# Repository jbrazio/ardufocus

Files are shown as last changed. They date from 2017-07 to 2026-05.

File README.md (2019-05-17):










**Ardufocus - The most accurate Open Source focus controller.**

Ardufocus is the only OSS/OSH controller supporting **two independent** focusing motors, **high resolution**
mode allowing **sub μm** movements by step, multiple acceleration profiles and it will never forget your
focuser position between restarts.

Ardufocus is a multi repository project:
- [Ardufocus firmware](https://github.com/jbrazio/ardufocus)
- [Ardufocus schematics](https://github.com/jbrazio/ardufocus-schematics)
- [Ardufocus ASCOM IFocuserV3 Driver](https://github.com/jbrazio/ardufocus-ascom)

Ardufocus is licensed under [GNU GPLv3](https://www.gnu.org/licenses/gpl-3.0.en.html). <br />
Ardufocus PCB schematics are licensed under [CC BY-NC-SA 4.0](https://creativecommons.org/licenses/by-nc-sa/4.0/).

----

### For documentation, tutorials and howto visit [ardufocus.com](https://ardufocus.com).

----

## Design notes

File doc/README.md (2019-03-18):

# Disclaimer

Unless otherwise noted, all materials contained in this repository are copyrighted
Copyright (C) 2017-2019 João Brázio [joao@brazio.org] and licensed under GPLv3.

The following materials are property of their respective owners:

- 28byj-48-bipolar-mod.pdf
- moonlite-dro-dual-focuser.pdf
- moonlite-focuser-protocol.pdf

## Fair Use

Copyright Disclaimer under section 107 of the Copyright Act of 1976, allowance
is made for “fair use” for purposes such as criticism, comment, news reporting,
teaching, scholarship, education and research.

## Fair Use Definition

Fair use is a doctrine in United States copyright law that allows limited use
of copyrighted material without requiring permission from the rights holders,
such as commentary, criticism, news reporting, research, teaching or scholarship.
It provides for the legal, non-licensed citation or incorporation of copyrighted
material in another author’s work under a four-factor balancing test.

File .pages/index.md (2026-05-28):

---
layout: homepage
keywords:

title: Ardufocus
description: |
  Ardufocus is the only OSS/OSH controller supporting <strong>two independent </strong>
  focusing motors, <strong>high resolution</strong> mode allowing <strong>sub μm</strong> movements
  by step, multiple acceleration profiles and it will never forget your focuser position between restarts.

buttons:
    - icon: chevron-right
      content: Firmware
      url: 'https://github.com/jbrazio/ardufocus/releases'
      external_url: true

    - icon: chevron-right
      content: Schematics
      url: 'https://github.com/jbrazio/ardufocus-schematics/releases'
      external_url: true

    - icon: chevron-right
      content: ASCOM Driver
      url: 'https://github.com/jbrazio/ardufocus-ascom/releases'
      external_url: true

author:
    title: About the Author
    title_url: 'https://github.com/jbrazio'
    external_url: true
    description: Nerd, geek, maker and part-time human being.

grid_navigation:
    - title: Getting started
      excerpt: >
        In this section you'll find basic information about Ardufocus. If you're first time user
        then you should read Getting Started section first.
      cta: Read more
      url: '/manual/getting-started/'

    - title: Hardware
      excerpt: >
        In this section we layout a quick overview of the main hardware used by Ardufocus so you can
        select the best hardware combination for your use case.
      cta: Read more
      url: '/manual/hardware/'

    - title: Build instructions
      excerpt: >
        It's time to get your hands dirty, learn which components you require for this
        project and learn howto build one for yourself.
      cta: Read more
      url: '/manual/build-instructions/'

    - title: Firmware
      excerpt: >
        In this section you'll find all the information you need to know to build and flash
        Ardufocus into your Arduino board.
      cta: Read more
      url: '/manual/firmware/'

    - title: ASCOM Driver
      excerpt: >
        This section will guide you around the ASCOM driver installation, a tour around the simple
        GUI and example configurations for common capture software.
      cta: Read more
      url: '/manual/ascom-driver/'

    - title: Tutorials
      excerpt: >
        Miscellaneous group of documents were each document will stand on it's own and will provide
        step by step instructions on how to do accomplish something.
      cta: Open Category
      url: '/howto/'
---

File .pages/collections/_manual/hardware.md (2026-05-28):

---
layout: default
keywords:
comments: false

tags: [ manual ]

title: Hardware
description: >
  In this section we layout a quick overview of the main hardware used by Ardufocus so you can
  select the best hardware combination for your use case.

micro_nav: true

page_nav:
    prev:
        content: Getting Started
        url: '/manual/getting-started/'

    next:
        content: Build instructions
        url: '/manual/build-instructions/'
---

### Processor
Ardufocus firmware supports the following AVR 8-bit microcontrollers. Currently there are no plans
to support additional architectures such as ARM but if you have a specific use case for it open a
[new feature request] and we will discuss it.

[new feature request]: {{ site.github.issues_url }}

| Microcontroller | Flash | SRAM  | EEPROM  |
|---|---|---|---|
| ATmega168 | 16KB  | 1KB | 512B |
| ATmega168P | 16KB  | 1KB | 512B |
| ATmega328P | 32KB  | 2KB |  1KB |
| ATmega328PB | 32KB  | 2KB |  1KB |
| ATmega32U4 | 32KB  | 2.5KB |  1KB |

Ardufocus uses as the brain for the operations the Arduino development board but the Arduino framework
aka IDE is not a build dependency for this project. Ardufocus is written in AVR C++.

The following boards have been tested and are fully supported:

| Board Name | Microcontroller | Clock  | Logic |
|---|---|---|---|
| Arduino UNO | ATmega328P | 16 MHz | 5V  |
| Arduino Nano 2.0 | ATmega168 | 16 MHz | 5V  |
| Arduino Nano 3.0 | ATmega328P | 16 MHz | 5V  |
| Arduino Nano 3.0 CN | ATmega328PB | 16 MHz | 5V  |
| Arduino Mini | ATmega168P | 16 MHz | 5V  |
| Arduino PRO Mini | ATmega328P | 16 MHz | 5V  |
| Sparkfun PRO Mini 3.3V | ATmega32U4 |  8 MHz | 3.3V  |

The serial support for the Sparkfun PRO Mini board is only avaliable for the internal *USART1*
broken out on pins `TX0` and `RX1`.

Some Arduino Nano clones coming from China use the *ATmega328PB* variant, despite being compatible
with the standard *ATmega328P* you may have some trouble getting the Arduino IDE to upload the
sketch into them. If this is your case [follow this tutorial] about properly stetting up the IDE
environment for working with those micros.

[follow this tutorial]: #

<div class="callout callout--warning">
  <p><strong>Memory constrains</strong> The usage of a microcontroller with less than 32KB of
  flash memory is currently barely supported as the firmware will use almost all of the available
  flash space. For future proof implementations it is strongly recommended to use one of the 32KB
  based boards.</p>
</div>

We recommend the usage of an [Arduino Nano 3.x] board.
This is a compact board, has enough *DIO* pins to handle two independent focuser motors and has
on-board Serial USB connectivity.

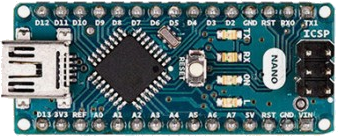
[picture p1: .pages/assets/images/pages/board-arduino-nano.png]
Arduino Nano


[Arduino Nano 3.x]: https://www.banggood.com/3Pcs-ATmega328P-Nano-V3-Controller-Board-Compatible-Arduino-Improved-Version-p-983486.html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

The following table represents the translation between IO `pins` as defined on the Arduino lingo and
their numeric equivalent on the Ardufocus configuration files, it also list the `pin` type and if it
defined on the Ardufocus's Hardware Abstraction Layer (HAL), pins not defined on the HAL are not
usable.

| Type | Arduino | PIN | HAL |
|---|---|-----|-----|
| Digital | D0 | 0 | Yes |
| Digital | D1 | 1 | Yes |
| Digital | D2 | 2 | Yes |
| Digital | D3 | 3 | Yes |
| Digital | D4 | 4 | Yes |
| Digital | D5 | 5 | Yes |
| Digital | D6 | 6 | Yes |
| Digital | D7 | 7 | Yes |
| Digital | D8 | 8 | Yes |
| Digital | D9 | 9 | Yes |
| Digital | D10 | 10  | Yes |
| Digital | D11 | 11  | Yes |
| Digital | D12 | 12  | Yes |
| Digital | D13 | 13  | Yes |
| Analog  | A0 | 14  | Yes |
| Analog  | A1 | 15  | Yes |
| Analog  | A2 | 16  | Yes |
| Analog  | A3 | 17  | Yes |
| Analog  | A4 | 18  | Yes |
| Analog  | A5 | 19  | No  |
| Analog  | A6 | 20  | No  |
| Analog  | A7 | 21  | No  |

### Stepper driver

| Driver | Current | Microsteps | VCC |
|---|---|---|---|
| [A4988] | 2A | 16 | 8-35V |
| [DRV8825] | 2.5A | 32 | 8-45V |
| [ULN2003] | 0.5A | 1 | 5-50V |

<div class="callout callout--info">
  <p><strong>ULN2003</strong> Actually the ULN2003 isn't a stepper motor driver but instead
  a Darlington Transistor Array on a single IC package thus all the pulse-train's timming and any
  additional microstepping needs to be generated by the microcontroller.</p>
</div>

Due to the wide usage of "step sticks" on 3D printers, the price difference between them and simpler
ULN2003 are virtually negligible when sourcing from generic manufacturers.

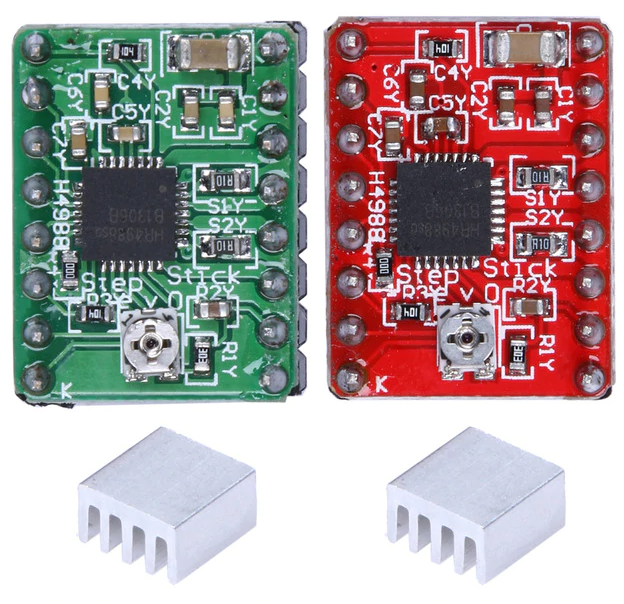
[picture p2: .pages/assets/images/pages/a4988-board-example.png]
A4988


The A4988 or the DRV8825 stepper motor driver have a lot of advantages when compared with the
ULN2003 darlington transistor array:

- Microstepping
- Adjustable current limiting
- Over-current and over-temperature protection
- 8-25V @ 1A without requiring a heat sink or forced air flow

[A4988]: https://www.banggood.com/3Pcs-3D-Printer-A4988-Reprap-Stepping-Stepper-Step-Motor-Driver-Module-p-967057.html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
[DRV8825]: https://www.banggood.com/3Pcs-3D-Printer-Stepstick-DRV8825-Stepper-Driver-Reprap-4-Layer-PCB-p-1052018.html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
[ULN2003]: https://www.banggood.com/3pcs-ULN2003-Four-phase-Five-wire-Driver-Board-Electroincs-Stepper-Motor-Driver-Board-p-1352783.html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

### Stepper motor
Ardufocus supports two types of stepper motors depending on the selected stepper driver.
Bipolar stepper motors are commonly known as [NEMA17] and have four leads.
Unipolar stepper motors are more uncommon and have five leads, the best known example is the [28BYJ-48].

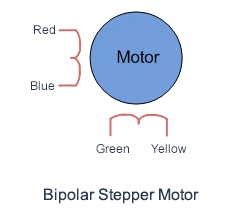
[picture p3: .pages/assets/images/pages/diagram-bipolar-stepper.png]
Bipolar Stepper Motor

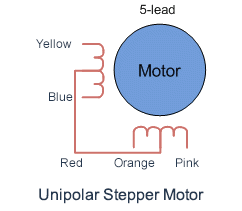
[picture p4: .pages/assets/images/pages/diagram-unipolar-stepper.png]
Unipolar Stepper Motor


Step stick drivers such as the A4988 or DRV8825 will drive Bipolar Stepper Motors like most
NEMA17 motors. The ULN2003 can drive either motor type but Ardufocus only supports Unipolar
Stepper motors when using the ULN2003 driver.

Unipolar stepper motors such as the 28BYJ-48 can be physically converted into a Bipolar type.
For more information have a look at the [following guide].

The table bellow represents typical values for both stepper motor types, you should always confirm
the specs for your specific motor by reading the manufacturer data sheet. Only for reference I provide
links for very common models of the [NEMA17](https://www.sparkfun.com/datasheets/Robotics/SM-42BYG011-25.pdf)
and [28BYJ-48](http://www.geeetech.com/Documents/Stepper%20motor%20datasheet.pdf) stepper motors.

| Type | I | Angle | Torque  | Gear | Steps/Rev |
|---|---|---|---|---|---|
| Bipolar  | 0.9A | 0.9 | 0.34N.M | 1:1  | 200 |
| Unipolar | 0.2A | 5.625 | 0.08N.M | 64:1 | 2038 |

<div class="callout callout--danger">
  <p><strong>Stepper motor voltage</strong> If you intend to use an Unipolar motor with the ULN2003
  driver please pay special attention to the motor's nominal voltage because this driver does not allow
  the user to set a current limit. 28BYJ-48 stepper motors are commonly available at 5V and 12V
  ratings, we recommend the 12V version.</p>
</div>

In terms of pricing, [NEMA17] motors are much more expensive than the [28BYJ-48]. You can buy a
[NEMA17] in the $15 range while a [28BYJ-48] motor will cost you only $2.

The main advantage of using a NEMA17 is the 5% accuracy range per step and the higher torque which
allows heavier payloads. As it is recommended to use backlash compensation on the focusing software,
the step accuracy between the two motor types is not that relevant.

[NEMA17]: https://www.banggood.com/FLSUN-2PCS-4-LEAD-Nema17-42BYGH-1_7A-Stepper-Motor-For-3D-Printer-p-1263976.html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
[28BYJ-48]: https://www.banggood.com/KittenBot-2Pcs-28BYJ-48-5V-DC-Stepper-Motor-4-Phase-5-Line-for-Smart-Robot-DIY-Part-p-1287817.html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
[following guide]: {{ '/howto/28BYJ-48-bipolar-hw-mod/' | relative_url }}

### Temperature sensor

<div class="callout callout--warning">
  <p><strong>TODO</strong> This section needs further improvement.</p>
</div>

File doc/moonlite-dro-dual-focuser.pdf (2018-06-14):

## Using a MoonLite DRO Dual controller with two

focusers.

Introduction.
It is possible to use the MoonLite DRO Dual port controller with two focusers rather than the normal configuration of one focuser and one rotator. This paper describes how to do this.
This control is only available through the ASCOM driver. The stand alone driver assumes that the second port is connected to a rotator.
Set up.
- Install the ASCOM DRO focuser and rotator driver.
- Select both the second Focuser and the second Rotator options, even though you don’t plan to use the rotator. The driver will try to connect as a rotator because it doesn’t know that one is not required.

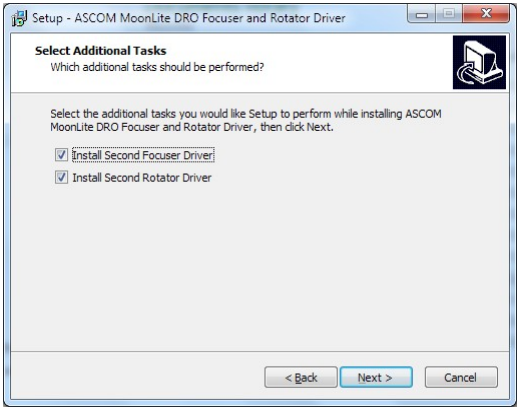
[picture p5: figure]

- Connect the two focusers, one to each port.
- For the first focuser:
- Select MoonLite DRO Focuser Driver
- Click on Properties:

- Set Motor 1 to be a focuser and set up the focuser:

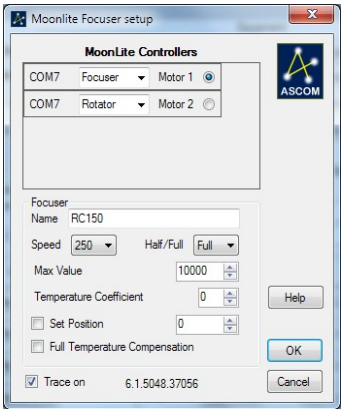
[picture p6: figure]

- Click on OK.
- For the second focuser:
- Select Second MoonLite DRO Focuser Driver
- Click on Properties:

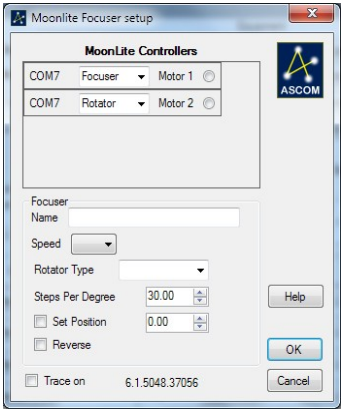
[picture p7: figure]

- Use the combo box to set Motor 2 to be a Focuser instead of a rotator and select it:

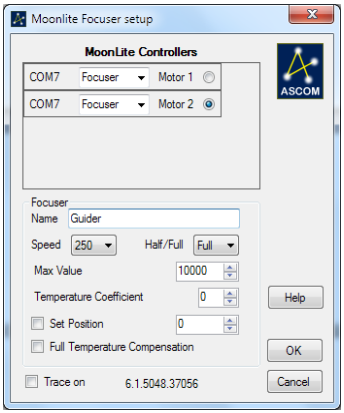
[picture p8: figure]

- Set up the values, including the name for that focuser and click on OK.

You should now be able to connect to and control both focusers.

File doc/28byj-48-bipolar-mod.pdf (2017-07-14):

ZONDAG 27 OKTOBER 2013
Change unipolar 28BYJ-48 to bipolar stepper motor
Now here's something I was not expecting. Previously, I tried to drive this stepper motor (http://www.jangeox.be/2013/10/stepper-motor-28byj-48_25.html) with the driver board that came with the motor. My main goal was of course keeping the accuracy of the tiny motor safe and then testing at which speed I could get the maximum torque it could produce. Depending on the driving method, I came up with 300gcm when it was driven using half stepping and 380gcm when I switched to full stepping. Those were actually good results considering that the datasheet predicted these numbers more or less.

Now this kind of motor is not really up-to-date with modern technology. Unipolar stepper motors are not that common anymore. Bipolar steppers are twice as efficient with the same amount of copper on the internal windings. Even in full stepping mode, a unipolar stepper still has 2 out of four wires not active all the time. So basically, if there was a way to run current through all windings in the motor at all times, the thing would be stronger and faster.

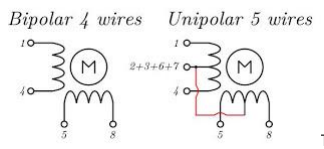
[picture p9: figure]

That's what happens in a bipolar stepper motor. It has only two windings instead of four in a unipolar stepper. Both windings can be activated all the time, but their polarity is switched in four steps. This means that this kind of motor only has four wires instead of 5 (or 6 or 8). The tricky part is changing the polarity. That cannot be achieved by the simple driver board that came with this motor. It only activates one or two out of four outputs, but current always flows in one direction.

What if we could change the wiring of this motor, thus converting it to a bipolar model? All you would need to do is cut the red wire in the scheme above and then ignore the center connection marked 2+3+6+7. The result would be something like the left drawing.

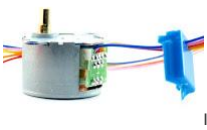
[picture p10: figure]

I found out that this is very easy with this motor. All you need is a sharp knife and a tiny screwdriver. Use the latter to remove the blue plastic cap that hides a small PCB. On this PCB, you can see eleven solder points. All it does is fixate the wiring of this stepper (which can be either unipolar or bipolar by design) into a unipolar type by connecting the center of the two windings. If we cut this connection and ignore it in our scheme, what's left is a real bipolar stepper motor.

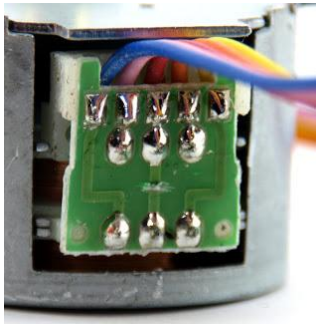
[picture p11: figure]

This is what the PCB looks like in detail. The red connection in the scheme above is actually the copper connection in this picture that I cut with a cutter knife. That's all you need to do! Well, for your own peace of mind, you could also try to re-attach the blue plastic cover. And now, ignore the red wire of the motor. We don't need it anymore.

But now we have a motor without a driver board. What you need is a H-bridge type which luckily exists in small packages if you're not going to drive heavy machinery. I used a L293D 16 pins DIP chip which I found online for $5.5 for ten chips.

I drew up this scheme that I used to drive the motor with an Arduino (actually I used an Atmega8 on a breadboard doing exactly the same thing, only a bit slower). I'm using 9V on the motor in this test since windings are twice as long as in the original version. I guess you could go much higher than that, this thing never heated up in my test.

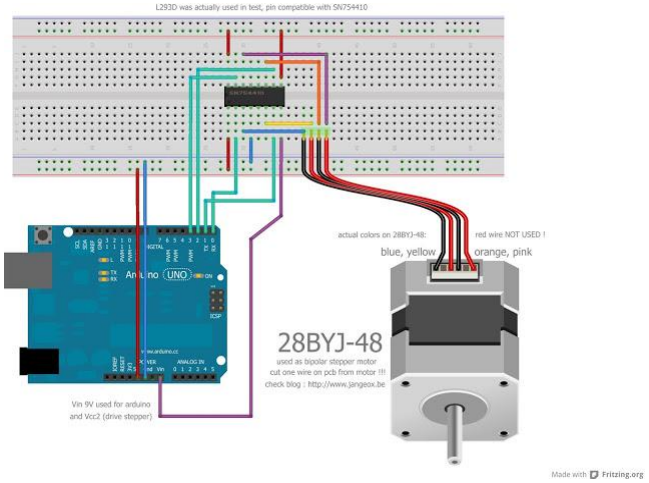
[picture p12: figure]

My simple code example to drive it can be found here. (http://printplussupport.be/28BYI_48_bipolar.html)

Finally, most importantly, my torque test resulted in :

800gcm !!

which is at least twice as much as full stepping unipolar (380gcm) and almost 3x more powerful than my half stepping unipolar test (300gcm)

Basically, if I cut one wire in the motor, it gains almost 3 times its original strength.

I like it! A lot! :)

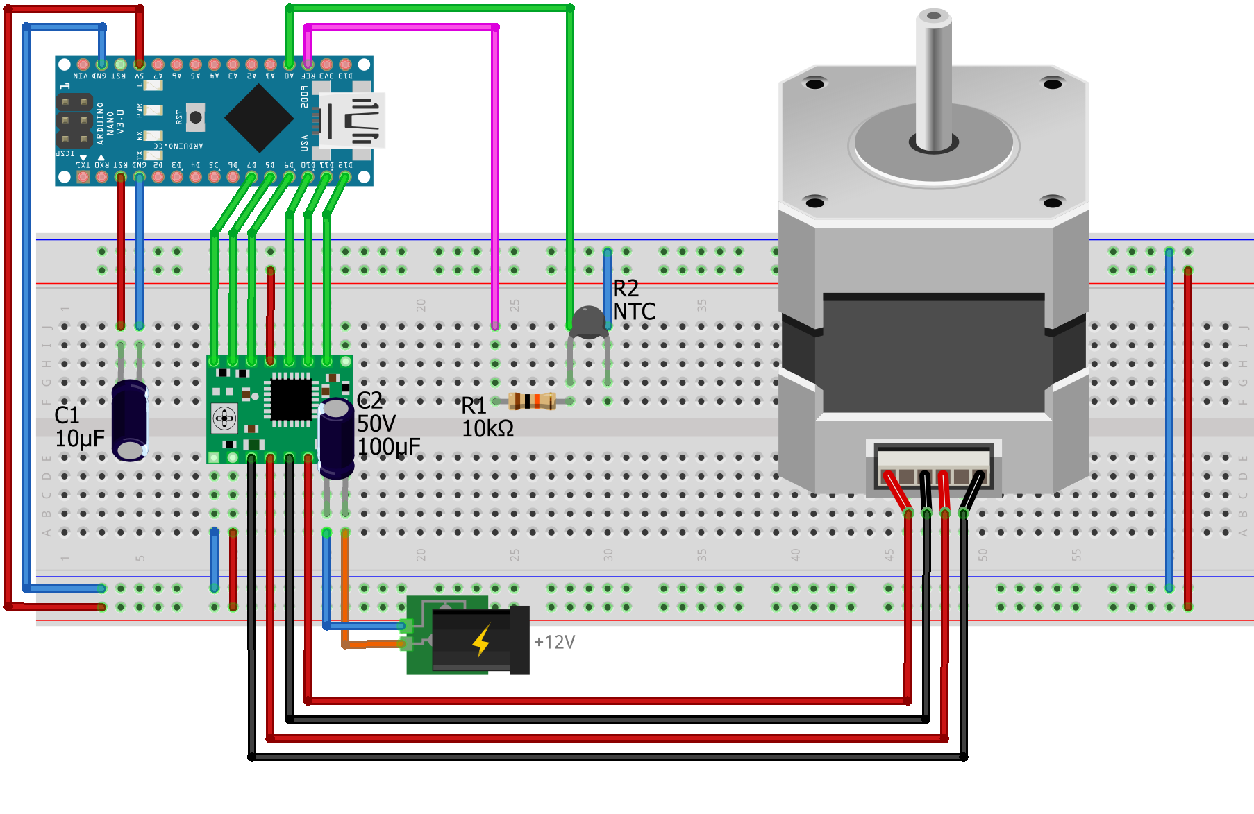
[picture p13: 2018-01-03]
doc/wiki/schematic-bipolar_bb.png

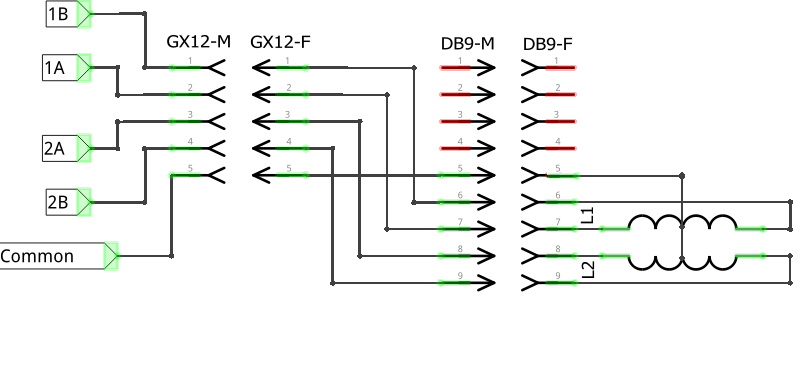
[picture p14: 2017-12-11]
doc/wiki/pinout-unipolar.png

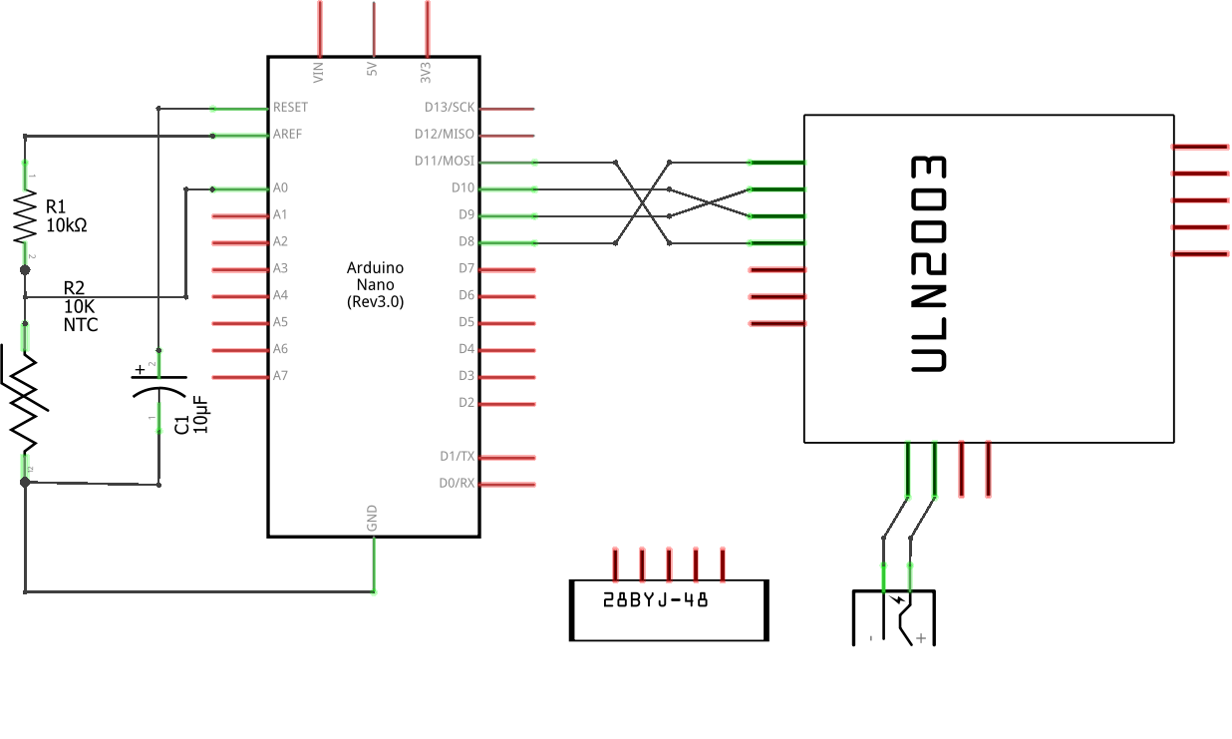
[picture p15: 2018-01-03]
doc/wiki/schematic-unipolar_schem.png

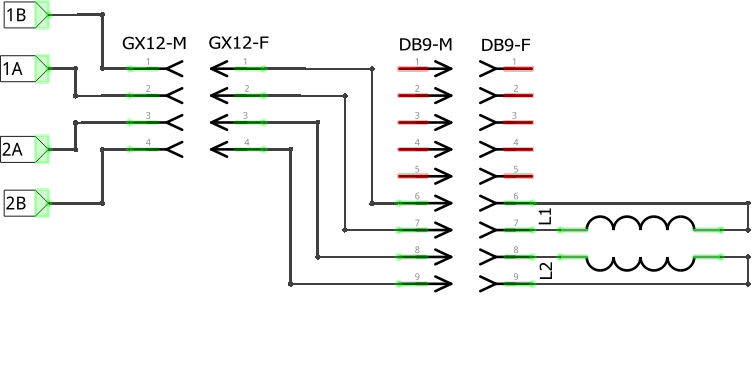
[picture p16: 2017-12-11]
doc/wiki/pinout-bipolar.png

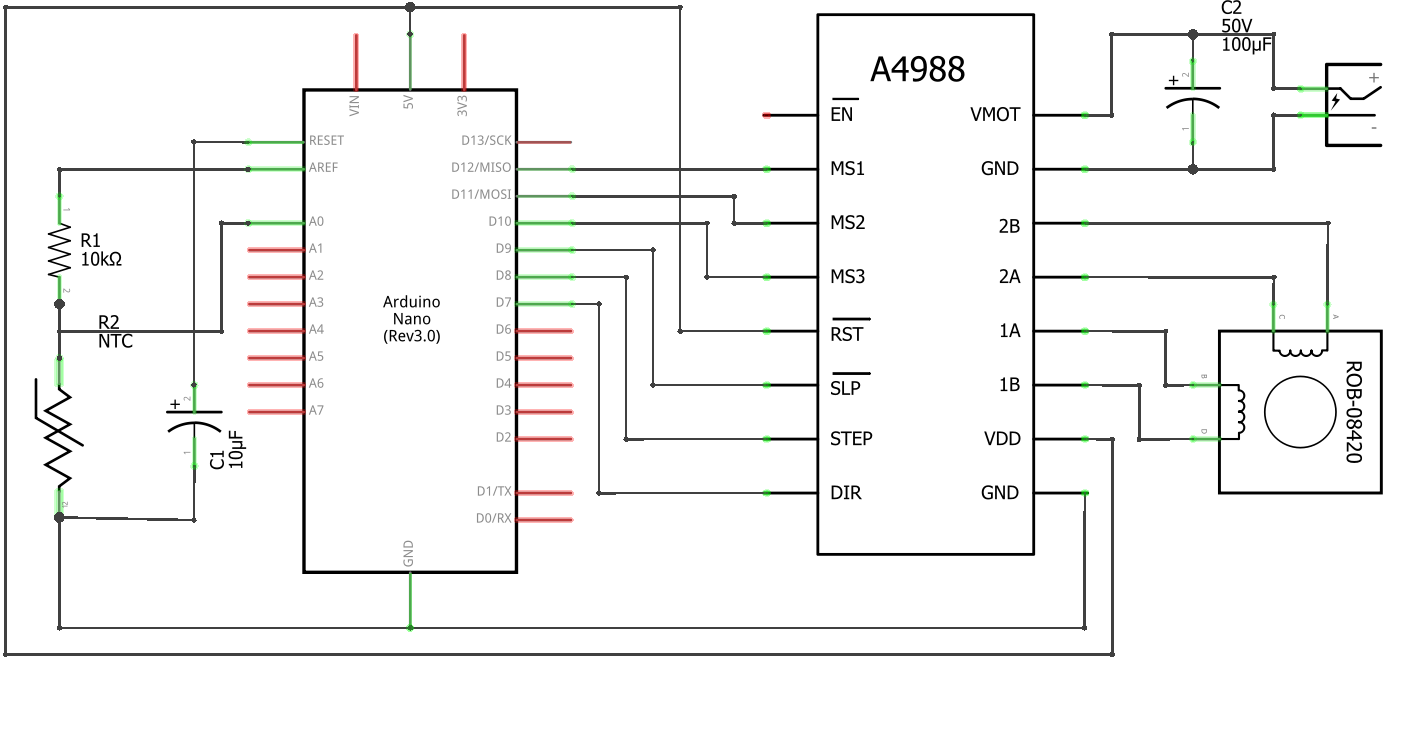
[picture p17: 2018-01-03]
doc/wiki/schematic-bipolar_schem.png

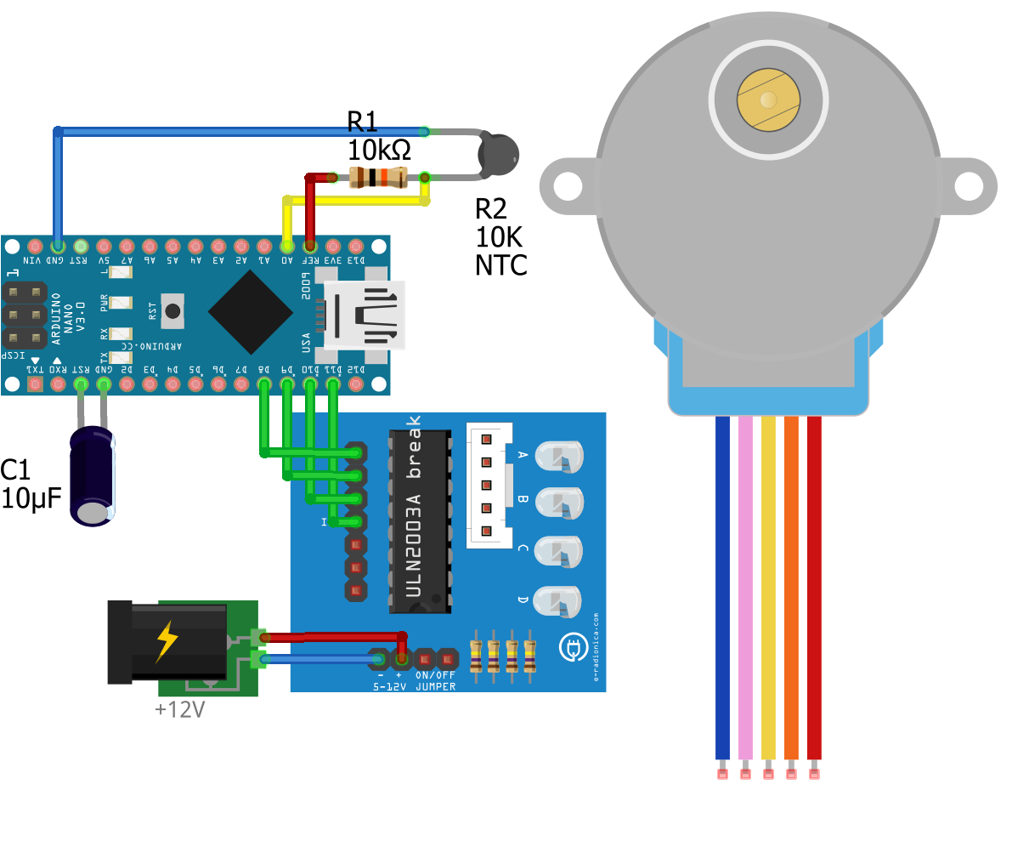
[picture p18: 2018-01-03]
doc/wiki/schematic-unipolar_bb.png

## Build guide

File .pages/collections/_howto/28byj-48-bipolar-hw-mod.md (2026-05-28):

---
layout: default
keywords:
comments: false

tags: [ howto ]

title: 28BYJ-48 Bipolar Mod
description: >
  This tutorial will teach you how you can convert easily the Unipolar 28BYJ-48 stepper motor into
  a Bipolar one.

micro_nav: true
---

## Introduction
The [28BYJ-48] is out of the factory a Unipolar Stepper Motor which, nowadays, are not that common
anymore. Bipolar stepper motors are considered to be at least twice as efficient as an Unipolar motor
for the same amount of copper on the windings.

Bipolar Stepper Motor
Unipolar Stepper Motor

According to [research done by Jan Adriaensen] the [28BYJ-48] in an Unipolar configuration can produce
300g.cm of torque half stepped and 380g.cm when full stepped, after the Bipolar mod you can expect
the motor to produce **800g.cm** of torque, that's around 3x more efficient !

[research done by Jan Adriaensen]: http://www.jangeox.be/2013/10/stepper-motor-28byj-48_25.html

## Modding the motor
To perform the hardware mode is quite simple, just pry open the blue plastic cover having special
attention not to hurt yourself, there are two plastic tabs one on each side of the cover which need
to break free in order for the cover to come out. This may require a bit of force.

After the cover is out the PCB will be exposed, you'll see three main thick traces, take a hobby
knife and cut the middle trace by scrapping the PCB varnish and copper. In the end you should have
a 1-2mm gap on the trace.

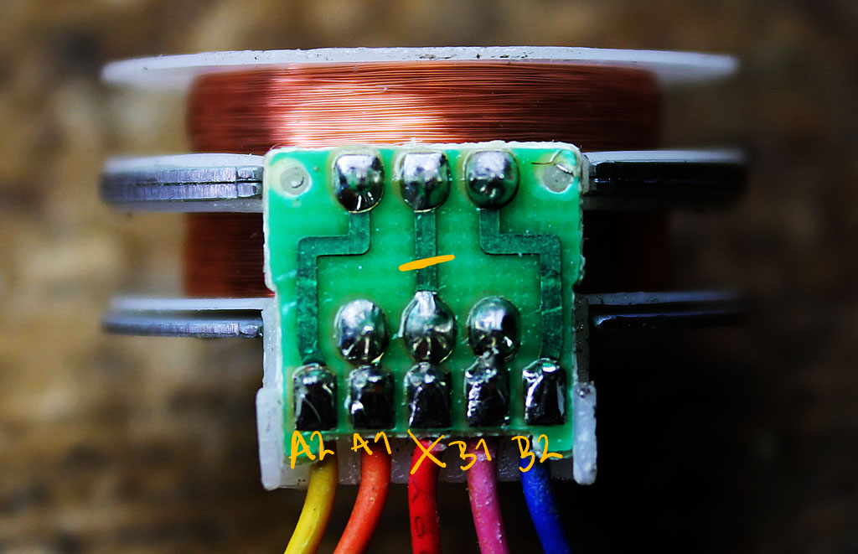
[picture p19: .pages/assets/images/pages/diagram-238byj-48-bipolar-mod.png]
PCB mod


The new motor windings will be **1** (Orange, Pink) and **2** (Yellow, Blue), you may cut the red
wire on unsolder it from the PCB.

| Color  | Winding | Side |
|---|---|---|
| Yellow | 2 | A |
| Orange | 1 | A |
| Red | N/A | N/A  |
| Pink | 1 | B |
| Blue | 2 | B |

## Driver
After performing the mod we can no longer use the [ULN2003] board to drive the stepper motor, we now
need a "H-Bridge" type of driver such as the [A4988] or the [DRV8825].

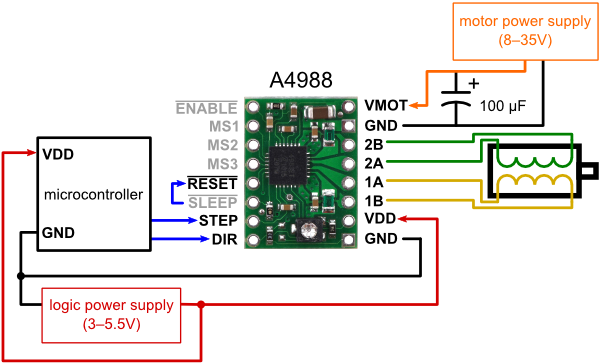
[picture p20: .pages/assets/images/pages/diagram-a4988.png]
A4988 schematic


[A4988]: https://www.banggood.com/3Pcs-3D-Printer-A4988-Reprap-Stepping-Stepper-Step-Motor-Driver-Module-p-967057.html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
[DRV8825]: https://www.banggood.com/3Pcs-3D-Printer-Stepstick-DRV8825-Stepper-Driver-Reprap-4-Layer-PCB-p-1052018.html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
[ULN2003]: https://www.banggood.com/3pcs-ULN2003-Four-phase-Five-wire-Driver-Board-Electroincs-Stepper-Motor-Driver-Board-p-1352783.html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
[28BYJ-48]: https://www.banggood.com/KittenBot-2Pcs-28BYJ-48-5V-DC-Stepper-Motor-4-Phase-5-Line-for-Smart-Robot-DIY-Part-p-1287817.html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

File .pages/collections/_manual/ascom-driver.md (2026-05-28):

---
layout: default
keywords:
comments: false

tags: [ manual ]

title: ASCOM Driver
description: >
  This section will guide you around the ASCOM driver installation, a tour around the simple
  GUI and example configurations for common capture software.

micro_nav: true

page_nav:
    prev:
        content: Firmware
        url: '/manual/firmware/'

    next:
        content: Tutorials
        url: '/howto/'
---

<div class="callout callout--warning">
  <p><strong>TODO</strong> This section needs further improvement.</p>
</div>

Ardufocus is 100% compatible with the Moonlite focuser protocol thus the original single-motor
drivers can be used for manual control of the unit, if you need to integrate with SGP, APT or any
other ASCOM based software then the universal ASCOM driver should be installed.

- [Moonlite's manual focus control](https://focuser.com/media/Downloads/MoonLite_Software/NonAscom/MoonliteSingleFocuser_v1.4.zip)
- [Moonlite's Universal ASCOM driver](https://focuser.com/media/Downloads/MoonLite_Software/Ascom/MoonLite%20DRO%20Setup.zip)

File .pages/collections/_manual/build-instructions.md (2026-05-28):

---
layout: default
keywords:
comments: false

tags: [ manual ]

title: Build instructions
description: >
  It's time to get your hands dirty, learn which components you require for this
  project and learn howto build one for yourself.

micro_nav: true

page_nav:
    prev:
        content: Hardware
        url: '/manual/hardware/'

    next:
        content: Firmware
        url: '/manual/firmware/'
---

## Motor Connections
### Unipolar

The Unipolar motor connection is straight forward because both the motor and the **ULN2003** board usually
come with a **JST-XH** connector. But nevertheless the table bellow lists the correct connections between
the two components.

| Color  | Winding | Side | ULN2003 |
|---|---|---|---|
| Blue | 2 | B | A |
| Pink | 1 | B | B |
| Yellow | 2 | A | C |
| Orange | 1 | A | D |
| Red | N/A | N/A  | +12V |

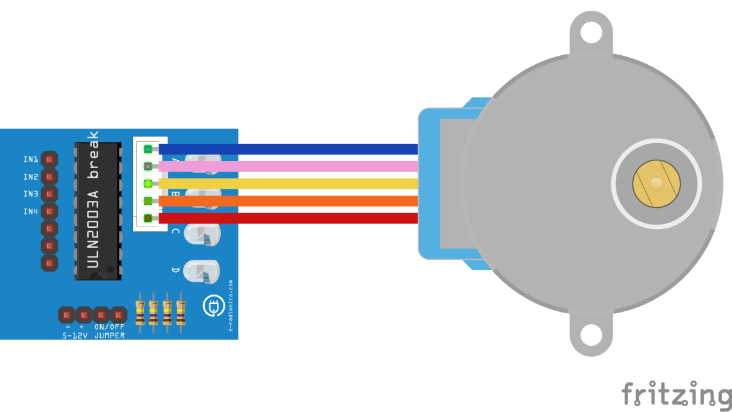
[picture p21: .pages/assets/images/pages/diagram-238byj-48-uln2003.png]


Remember to enable `#define MOTOR1_USE_ULN2003_DRIVER` on your `config.h` file, for more information
check the [firmware page].

### Bipolar
Bipolar stepper motors are only supported by Ardufocus when using a step stick, due to the multiple
motors and connectors available on the market it's hard to specify which one will be the correct one
in use at your configuration but nevertheless there are some tricks that will ease your job finding
the correct connections.

#### NEMA17
All NEMA motors have only four wires, to find the correct windings just grab your multimeter and set
it for resistance measurement. Label each one of the wires from 1 to 4 and then take any random two
and measure the resistance between them, either you'll get a reading or a open circuit. Keep
measuring different wires until you get the two pairs that give you a reading between them and that's
your two coils.

Let's assume wire `1 and 3` form a pair and `2 and 4` form the other pair, to connect it to the step
stick connect `wire 1` to `2B`, `wire 3` to `2A`, `wire 2` to `1B` and `wire 4` to `1A`.

#### 28BYJ-48

The table bellow shows the connections between the **28BYJ-48** motor and the **A4988** step stick.

| Color  | Winding | Side |
|---|---|---|
| Blue | 2 | B |
| Yellow | 2 | A |
| Orange | 1 | A |
| Pink | 1 | B |
| Red | N/A | N/A  |

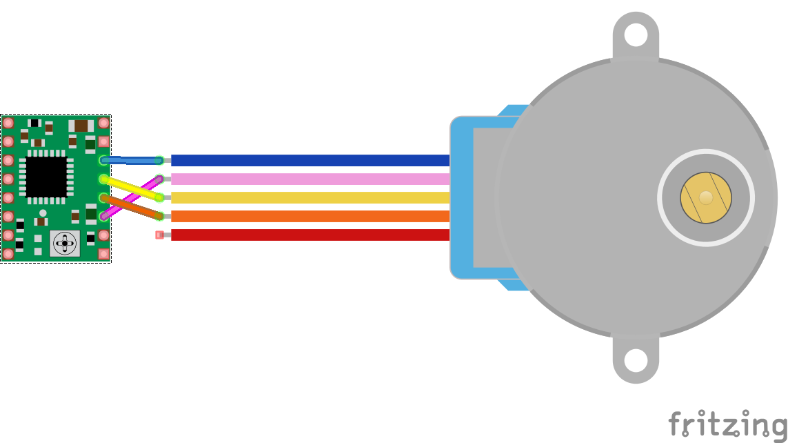
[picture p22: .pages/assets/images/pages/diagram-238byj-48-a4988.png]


Remember to enable `#define MOTOR1_USE_A4988_DRIVER` or `#define MOTOR1_USE_DRV8825_DRIVER` on your
`config.h` file, for more information check the [firmware page].

[firmware page]: {{ '/manual/firmware/#motor-configuration' | relative_url }}

## Breadboard

### 28BYJ-48 with ULN2003 driver
This build is the cheapest focuser you can have not only due it's bare bones approach but also due to
the it's minimal BOM, part count and availability of each item. **Use this configuration only with
unmodded 28BYJ-48 stepper motors**.

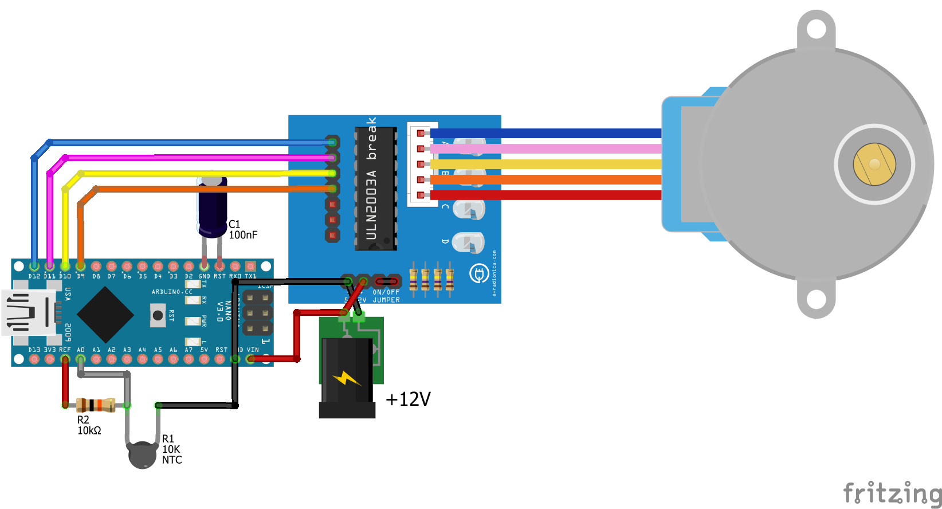
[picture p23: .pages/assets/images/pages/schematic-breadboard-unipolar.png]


#### BOM
Check the required BOM on the table bellow. The **100nF** capacitor is only required if you intend
to use Ardufocus in a Moonlite compatibility mode i.e. use Moonlite's ASCOM drivers, if you intend
to use Ardufocus ASCOM drivers then this capacitor is not required.

| Description | Specs | Qt |
|---|---|----|
| 28BYJ-48 stepper motor  | 12V | 1  |
| Arduino | Nano 3.0 | 1  |
| Driver break out board  | ULN2003 | 1  |
| Electrolytic Capacitor  | 100nF >12V | 1  |
| NTC | 10K | 1  |
| Resistor | 10KΩ 5% 1/4W | 1  |

#### Settings
Edit your `config.h` file and set make sure the options bellow are enabled.

```c++
#define MOTOR1_USE_ULN2003_DRIVER
#define MOTOR1_PINOUT 12, 11, 10, 9
```

#### Pinout

| PIN | Motor #1 | Motor #2 |
|---|---|---|
| IN1 | D12 | D08 |
| IN2 | D11 | D07 |
| IN3 | D10 | D06 |
| IN4 | D09 | D05 |

### 28BYJ-48 with A4988 driver
This solution is not so much more expensive nor complicated but will give you much more torque from
the exact same motor when compared with the Unipolar build. **Use this configuration only with
[modded 28BYJ-48 stepper motors]({{ '/howto/28byj-48-bipolar-hw-mod/' | relative_url }}) or with
NEMA17 stepper motors**. The example bellow shows a modded 28BYJ-48 but the connections for a
NEMA17 are exactly the same.

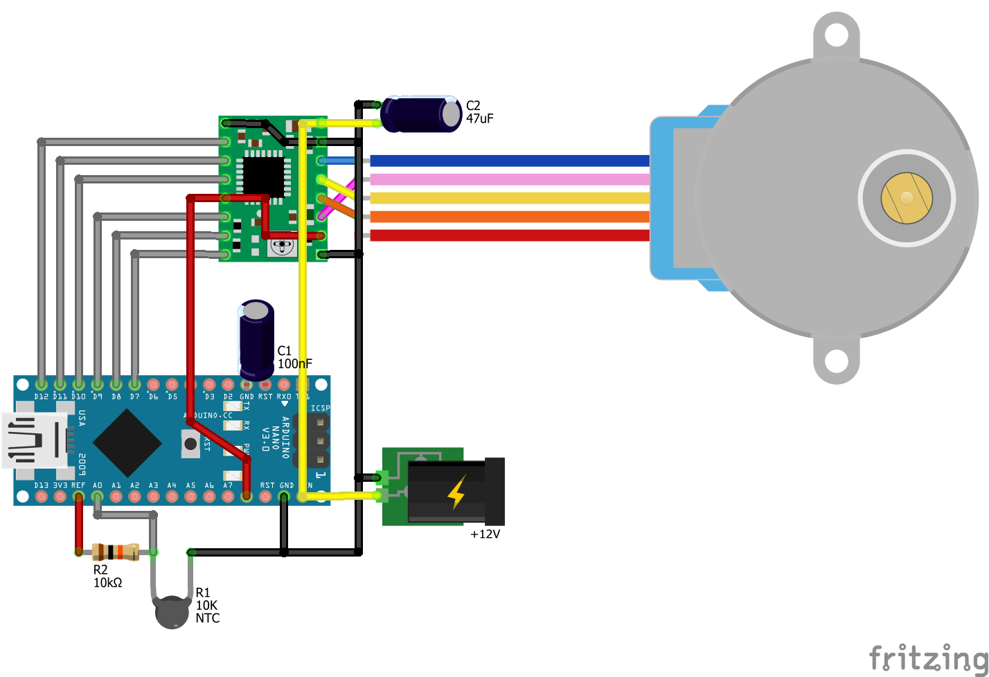
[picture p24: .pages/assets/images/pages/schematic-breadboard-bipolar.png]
28BYJ-48 and A4988


#### BOM
Check the required BOM on the table bellow. The **100nF** capacitor is only required if you intend
to use Ardufocus in a Moonlite compatibility mode i.e. use Moonlite's ASCOM drivers, if you intend
to use Ardufocus ASCOM drivers then this capacitor is not required.

| Description | Specs | Qt |
|---|---|----|
| 28BYJ-48 stepper motor  | 12V | 1  |
| Arduino | Nano 3.0 | 1  |
| Electrolytic Capacitor  | 100nF >12V | 1  |
| NTC | 10K | 1  |
| Resistor | 10KΩ 5% 1/4W | 1  |
| Step Stick | A4988 | 1  |

#### Settings
Edit your `config.h` file and set make sure the options bellow are enabled.

```c++
#define MOTOR1_USE_A4988_DRIVER
#define MOTOR1_PINOUT 12, 11, 10, 9, 8, 7
```

#### Pinout

| PIN | Motor #1 | Motor #2 |
|---|---|---|
| MS1 | D12 | A2 |
| MS2 | D11 | D6 |
| MS3 | D10 | D5 |
| RESET | NC | NC |
| SLEEP | D9 | D4 |
| STEP  | D8 | D3 |
| DIR | D7 | D2 |

## PCB

<div class="callout callout--warning">
  <p><strong>TODO</strong> This section needs further improvement.</p>
</div>

PCB Top

PCB Botttom

#### BOM

#### Settings

#### Pinout

| PIN | Motor #1 | Motor #2 |
|---|---|---|
| IN1 | D12 | D08 |
| IN2 | D11 | D07 |
| IN3 | D10 | D06 |
| IN4 | D09 | D05 |

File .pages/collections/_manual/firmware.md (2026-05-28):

---
layout: default
keywords:
comments: false

tags: [ manual ]

title: Firmware
description: >
  In this section you'll find all the information you need to know to build and flash
  Ardufocus into your Arduino board.

micro_nav: true

page_nav:
    prev:
        content: Build instructions
        url: '/manual/build-instructions/'

    next:
        content: ASCOM Driver
        url: '/manual/ascom-driver/'
---

## Introduction

If you have built the Moonlite compatible version then a capacitor is used on the Arduino's reset
line to keep it high during serial connect/disconnect which is mandatory for normal operation but
in order to flash the firmware to the board the capacitor must be disconnected, otherwise you need
to synchronize a manual push of the reset button when uploading to the board. Once again, this is
only necessary **if you have built the Moonlite compatible version**.

To enable a feature remove the comment tag `//` from the start of the line.
To disable a feature add  the comment tag `//` to the start of the line or delete the entire line.

```c++
// The option bellow is ENABLED
#define COOL_FEATURE_6000

// The option bellow is DISABLED
//#define COOL_FEATURE_6000
```
## Config options

### Overall
#### Persistent memory
Enable auto save of the focuser position uppon finishing each move. When
active the focuser will remember between power cycles the exact position
where it was.

```c++
#define USE_EEPROM
```

#### Remote reset
Remote reset is a non standard feature added to the Moonlite protocol which
allows you to reset the micro controller inside the focuser. Please test
this feature on your bench before deploying on the field. For this feature
to work the default boot loader may need to be changed otherwise the uC will
enter into an infinite loop state.

```c++
#define ENABLE_REMOTE_RESET
```

#### Serial DTR reset <sup>(beta)</sup>
Enable a subset of commands to control the status of the DTR auto-reset
feature on the Arduino boards. By default Ardufocus uses a cap between the
reset pin and ground to prevent the DTR signal to reset the board, which
happens every time a new serial connection is open to the board.
By having the cap between the reset pin and another board pin, enabling
this feature allows the DTR auto-reset to be controlled. This is useful
for firmware uploads, if the DTR auto-reset is disabled the user must
manually press the reset button when uploading new firmware.

```c++
#define ENABLE_DTR_RESET
```

This is the board pin which controls the enable/disable of the feature.

```c++
#define DTR_RESET_PINOUT 15
```

Activating this option will enable high resolution counters (32-bit) thus
becoming incompatible with the standard Moonlite protocol. You should enable
this if using a gearbox or having a millimetre threaded rod on the drive
mechanism.
```c++
#define HIGH_RESOLUTION_MODE
```

### Motor configuration

#### Driver
You should only enable *ONE* of the following drivers
The ULN2003 shall be used with the unmodded version of 28BYJ-48 or any other
Unipolar stepper motor. The A4988 driver should be used with Bipolar stepper
motors or the [modded version] of the 28BYJ-48, for more information see the
[hardware] section.

[modded version]: {{ '/howto/28BYJ-48-bipolar-hw-mod/' | relative_url }}
[hardware]: {{ '/manual/hardware/#stepper-motor' | relative_url }}

```c++
#define MOTOR1_USE_A4988_DRIVER
```

```c++
#define MOTOR1_USE_DRV8825_DRIVER
```

```c++
#define MOTOR1_USE_ULN2003_DRIVER
```

#### Pinout
Tells the firmware which pins should be used to control the driver.

```c++
//                    MS1, MS2, MS3, SLEEP, STEP, DIR
#define MOTOR1_PINOUT  12,  11,  10,     8,    7,   6
```

#### Direction
Activate the following directive if you'd like to invert the motor rotation
changing the focus direction.

```c++
#define MOTOR1_INVERT_DIRECTION
```

#### Sleep when idle
When active Ardufocus will cut the stepper motor current when idle, in theory
this could lead to less accuracy between movements but will keep the motor
cool. When disabling this flag make sure your motor does not overheat.

```c++
#define MOTOR1_SLEEP_WHEN_IDLE
```

#### Sleep timeout
When the previous directive is active, allows you to control the amount of
time the driver will wait, after stopping, before powering down the motor.
The idea behind is the system needs full accuracy between the AF point
sequence but can be powered down between AF runs. Thus you should set this
to wait a bit more than the time your system needs to take and measure each
AF point.

```c++
#define MOTOR1_SLEEP_TIMEOUT 15
```

#### Speed profile
Specify a custom speed profile for you motor model and driver combo.
The units are in steps/sec.

Usually a motor such as the 28BYJ-48 need lower speed limits:
 - Max speed: 250
 - Min speed: 25

NEMA17 motors allow you to use higher speed limits:
 - Max speed: 1000
 - Min speed: 250

```c++
#define MOTOR1_MAX_SPEED 150
#define MOTOR1_MIN_SPEED  25
```

#### Acceleration profile
When active Ardufocus will apply the selected acceleration profile to the
motor's speed. The objective is to help the system cope with heavier loads
such as FF + FW + CCD combos.

```c++
#define USE_LINEAR_ACCEL
```

```c++
#define USE_TRAPEZOID_ACCEL
```

```c++
#define USE_SMOOTHSTEP_ACCEL
```

The acceleration profile, independent of the method used, has at least two
main periods: the ramp-up period when the motor is gaining speed and the
ramp-down period when the motor is losing speed. This setting controls the
duration of each one of those periods, the default value is 250 steps for
each period if left undefined.

```c++
#define ACCEL_DURATION 250
```

When acceleration control is active this setting controls the minimum
required number of steps on a movement for the algorithm to kick in. Any
movement with less steps than this will be done at minimum speed without
any acceleration control. The default value is 10 steps of left undefined.

```c++
#define ACCEL_MIN_STEPS 10
```

### Temperature sensor

<div class="callout callout--warning">
  <p><strong>TODO</strong>Explain howto fine tune the values bellow.</p>
</div>

```c++
#define NTC_ADC_CHANNEL          0
#define NTC_NOMINAL_TEMP      25.0F
#define NTC_BCOEFFICIENT    3950.0F
#define NTC_NOMINAL_VAL    10000.0F
#define NTC_RESISTOR_VAL   10000.0F
```

Minimum value to be considered a valid reading (xxxC)

```c++
#define NTC_MIN_RAW_VALUE  50
```

Maximum value to be considered a valid reading (-23C)

```c++
#define NTC_MAX_RAW_VALUE 950
```

According to the Moonlite protocol the temperature probe should only be read
when the command `:C#` is received but some applications, such as SGP, seems
not to respect this and only call the get temperature command `:GT#` which
means the temperature will never get updated and the last read value is always
returned, either it is valid or not. Enabling the following option will force
the temperature gathering process on every temperature read command.

```c++
#define START_TEMP_CONVERSION_ON_EVERY_GET
```

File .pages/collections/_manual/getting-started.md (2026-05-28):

---
layout: default
keywords:
comments: false

tags: [ manual ]

title: Getting started
description: >
  In this section you'll find basic information about Ardufocus. If you're first time user then
  you should read Getting Started section first.

micro_nav: true

page_nav:
    next:
        content: Hardware
        url: '/manual/hardware/'
---

## Description
Ardufocus is a stepper motor controller designed from the ground up for astronomy usage, our aim is
to enable you to have the most accurate Open Source focus controller for a fraction of the price of
the commercial ones.

Ardufocus is **Open Source Software** and **Open Source Hardware** which means you have access to all the
firmware, software and hardware needed to build or modify the platform according to your preferences.

Using off-the-shelf components such as the Arduino Nano and easily available parts Ardufocus is
aimed to be build by anyone with a soldering iron and some patience, no degree in electronics required.

Another big point was to made it as cheap as possible recurring to as few parts as needed. That's
the reason why the 28BYJ-48 stepper motor was chosen, out-of-the-box using the ULN2003 gives you a
really cheap focuser for medium loads. If you require the focuser to driver heavier loads then the
motor itself can be physically modded into a Bipolar stepper motor and driven by the A4988 step
stick which will cost you in overall less than $10.

The project started by being a Moonlite protocol compatible focuser but in order to leverage some of
the new features such as High Resolution (32-bit integers), I am currently developing it's own custom
set of ASCOM IFocuserV3 drivers.

## Contribute
Ardufocus is a *one-man-army* kind of a project which I develop on my free time, if you use it please
help out by [spreading the love](spam) or, if you prefer to assure it's long-term continuity consider
one of the options bellow:




[spam]: #

## Key features
- Up to two independent steppers with only one controller
- Stepper position is kept between power cycles
- High resolution mode using 32-bit counters
- Multiple stepper drivers are supported
- Multiple acceleration profiles

### Additional features
- Moonlite protocol compatible
- Remote soft-reset of the microcontroller
- Enable/Disable of thee automatic reset on serial connection
- Allow motor direction inversion by software
- Automatic enter sleep mode when idle with use defined timeout
- User defined min, max and acceleration speeds
- Fine tune of NTC parameters

## Source code
Each Ardufocus module is located on it's own Github public repository:
- [Ardufocus firmware](https://github.com/jbrazio/ardufocus)
- [Ardufocus schematics](https://github.com/jbrazio/ardufocus-schematics)
- [Ardufocus ASCOM IFocuserV3 Driver](https://github.com/jbrazio/ardufocus-ascom)

## License
Ardufocus is licensed under [GNU GPLv3](https://www.gnu.org/licenses/gpl-3.0.en.html). <br />
Ardufocus PCB schematics are licensed under [CC BY-NC-SA 4.0](https://creativecommons.org/licenses/by-nc-sa/4.0/).

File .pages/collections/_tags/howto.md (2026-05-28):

---
layout: tags
comments: false
permalink: /howto/

tags: [ howto ]

title: Tutorials
description: |
  Miscellaneous group of documents were each document will stand on it's own and will provide step 
  by step instructions on how to do accomplish something.

micro_nav: true
---

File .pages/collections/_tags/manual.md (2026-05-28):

---
layout: tags
comments: false
permalink: /manual/

tags: [ documentation ]

title: Documentation
description: |
  This section will list all available tutorials.

micro_nav: true
---

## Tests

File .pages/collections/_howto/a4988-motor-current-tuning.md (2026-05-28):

---
layout: default
keywords:
comments: false

tags: [ howto ]

title: A4988 motor current tuning
description: >
  This tutorial will teach you how to fine tune the stepper motor current using the built-in
  potentiometer, a screw driver and a multimeter.

micro_nav: true
---

## Introduction
The A4988 stepper driver, originally made by Pololu, will interrupt the current to the motor for a
little while if the it gets too hot. If you haven't tuned your motor current at all, it may happen
that the motor doesn't move correctly and starts pulsating, it will stop as soon as you reduce the
current by rotating the pot.. this is clearly a sign you need to fine tune the motor current.

## Reference voltage
The A4988 allows you to set a target current anywhere between some mA up to a bit less than 2A, this
is accomplished by adjusting what is called the `Vref` (Reference Voltage) when turning the pot on a
clockwise direction the `Vref` voltage will increase and decrease when rotating it counterclockwise.

The actual value of `Vref` can be calculated using the formula:<br />
`Vref = Imax * 8 * Rs`

<div class="callout callout--info">
  <p><strong>DRV8825</strong> The equation for calculating <code class="highlighter-rouge">Vref</code>
  for this board is <code class="highlighter-rouge">Vref = Imax /2</code> when having a <b>0.1</b> Ω
  sensing resistor.</p>
</div>

## Sensing resistor
But first we need to find out the proper value of the current sensing resistor `Rs` as it's exact
value is dependent of the A4988 board manufacturer. By looking at the number marked on top of `R5`
you may use a tool such as [this one] to find out it's exact value in Ohms.
If you dont find `R5` search for `S1` or `S2`.

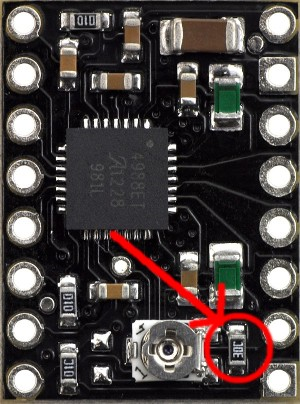
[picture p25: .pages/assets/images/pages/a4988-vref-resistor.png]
A4988 resistor value


Original Pololu boards have a **0.05** Ω resistor while most generic brands use **0.1** Ω.

Let's take the **0.1** Ω sensing resistor value as an example, just replace `Rs` on the formula like
so `Vref` using `Vref = Imax * 8 * 0.1`.

[this one]: https://www.hobby-hour.com/electronics/smdcalc.php

## A word about heat
The step stick is such a a small board, this is both it's strongest and weakest point. The small
form factor makes it an smart choise for projects where overall bulk size matters but also makes it
run hot as chilli. Some vendors provide you a stick-in heatsink, the performance improvement using
it is rather questionable so your best friend is de-rating the motor current.

If you have a motor which max current is spec at 2A, you should ran it at around 70% to 80% of that,
this will not only make your step stick happier but also the motor will run cooler.

## Adjusting the current
Let's take a 1.5A motor which we want to run at 80% of its rating:<br />
`Imax = 1.5 * 0.8 <=> Imax = 1.2A`

Let's also take a generic step stick having the sensing resistor (`Rs`) value of 0.1 Ω, take the
initial formula `Vref = Imax * 8 * Rs` and replace `Imax` and `Rs`.

`Vref = 1.2A * 8 * 0.1 <=> Vref = 0.96`

Using a multimeter measure the voltage across the top of the potentiometer head and any ground point
on the board.

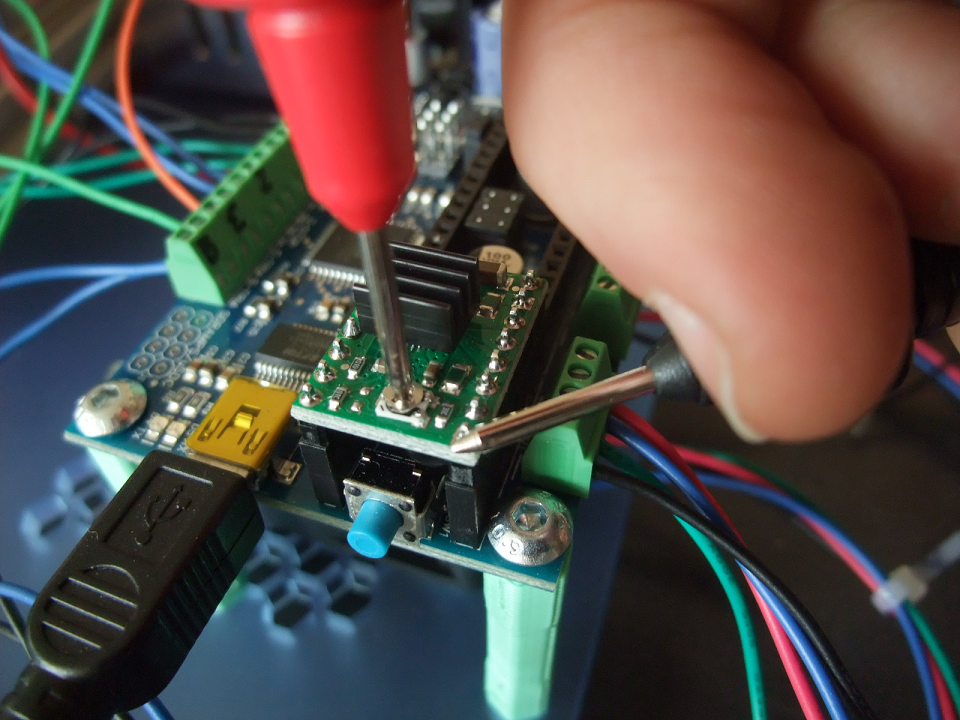
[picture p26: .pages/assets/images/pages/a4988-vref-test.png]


Adjust the pot until you measure, in this example, 0.96V.
Now you have your step stick properly adjusted for your motor's current.

<sup>All images on this document are copyright reprap.org and licensed under the GNU Free
Documentation License.</sup>

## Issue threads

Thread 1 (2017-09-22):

SGP won't connect

kingjamez, 2017-09-22:
Hi! Thanks for putting this up for us all to use! I've got ardufocus on a Arduino Nano. From the standalone Moonlight focusing software everything works. I can also control it as expected from putty to my COM port. However, SGP won't connect to the device.  When I sniff on the serial port, I see that the Ardufocus is sent :GH# and then it times out with no response. I can send :GH# through putty and I get a response.

jbrazio, 2017-09-29:
You may need to put the cap to hold the reset line, without it the ASCOM driver will not work.

jbrazio, 2017-09-30:
Closing after [discussion](https://www.cloudynights.com/topic/585306-ardufocus-open-source-moonlite-compatible-focuser/?p=8125666) on Cloudy Nights forum:

> I added the cap and it's all working perfectly now. I'm using the Moonlight DRO Focuser driver and I have excellent performance on my Moonlight High Res stepper motors. I needed to Mod the steppers in the moonlight unit to be bi-polar instead of unipolar, but they are six wire stepper motors, so I only had to cut one of the six wires and then my DRV8825 controlled the motor perfectly.

Closed 2017-09-30.

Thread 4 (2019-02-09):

Support for TMC2130 Silent StepStick

jrsphoto, 2019-02-09:
I've downloaded your code and I'm trying to figure out how I might go about adding support for the TCM2130 Silent Stepstick drivers. I've got a few from other projects and they have some very nice features that I think would be nice for use in a focuser.  They are complicated drivers but there are some nice Arduino libraries available, this one I've used in the past:

https://github.com/teemuatlut/TMC2130Stepper

Got any pointers as to how I would I go about adding this library, and support for its functions, to your ardufocus program

jbrazio, 2019-02-24:
Hi @jrsphoto ! This is something that already crossed my mind, specially because by using TCM2130 we would gain "free" endstops. My code is not 100% Arduino environment compatible, have you tried to include the libs ? At least you would need to create a new wrapper object to handle the specificities of TCM2130. I would suggest to have a look at [a4988.cpp](https://github.com/jbrazio/ardufocus/blob/master/ardufocus/a4988.cpp) and [a4988.h](https://github.com/jbrazio/ardufocus/blob/master/ardufocus/a4988.h).

Closed 2019-07-25.

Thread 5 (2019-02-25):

Switch for in/out focusing

opossome, 2019-02-25:
Hi !

Can you add support for 2 switchs doing in and out focusing , usefull for regular stargazing without loosing home and preset .
Actually using a basic sketch with switchs on D2 and D3 and fixed speed @ 300 steps/s . Adjustable speed will be great too , like long press --> increase speed and impulse for fine tuning .

Thx for your great job !

Ultimaboot, 2019-05-17:
I to find this a great idea. Is there any progress in code develpment and schematic trading?

Ultimaboot, 2019-05-17:
I to find this a great idea. Is there any progress in code develpment and schematic wiring?

jbrazio, 2019-05-17:
Hi @Ultimaboot I've added new features on the board revision I'm working on that will allow plug-able modules such as this one. The version you have it will require some patchwork but it's also doable.

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

I usually have the focuser box attached to the telescope itself, if the buttons are built-in then it would mean that pressing them would create oscillations.

Should this be a wired module or a built-in feature ? I'm really open to suggestions.

Ultimaboot, 2019-05-17:
You could make a small  control box with two buttons and connect this to the main box and not to the focus box. The connection on the main box could be RJ jack connection or something else. Or you could intergrate it on the main box. The speed could be adjustable with a pot or with fixed speed.

Ultimaboot, 2019-05-17:
I asome that the pcb modification has something the do with a display module and possible a HC module, correct?

jbrazio, 2019-05-18:
Indeed.. it can be used for an ESP (wireless), Bluetooth or the HC we are starting to design.

As we need the serial to be used by the USB port the HC could be done using the I2C protocol.. the overhead is adding another nano/mini to the HC itself.

I'm thinking instead of a pot add a small OLED display and maybe a three button interface ?

We let the user define three "speeds":
- Click speed
- Double click speed
- Long press speed

Like one click makes the motor move 5 steps into one direction, double click moves 50 steps and long press moves until you release it.

The third button would be use to allow the navigation on the menu items so the user can define the speeds and so without requiring a computer.

The connection between the HC and the focuser could be either wired (four way cable) or some kind of RF/Bluetooth.

What do you think ?

Ultimaboot, 2019-05-18:
Would be only a HC-05 Bluetooth module with smartphone control be a option.
There something like MIT App Inventor where can simply can make control functions like the one you mentions. No LED display would be needed and i think it would be cheaper to.
What do you think?

jbrazio, 2019-05-18:
Oh wait I read “HC” has in Hand Controller !

Yes that the Bluetooth module would go there directly, maybe with some 5V to 3.3V level shifter logic that some need.

But the problem já still there, either you have a focuser for visual or for automatic focus, because we only have one serial and we cannot use it for USB serial and Bluetooth serial.

Nevertheless I will check your App Inventor suggestion because it can indeed be useful. The only method I used before was React Native to code to both android and iOS in one go.

Ultimaboot, 2019-05-18:
There is something like Software Serial Library witch make it possible to make a second serial port.
[https://www.arduino.cc/en/Reference/SoftwareSerial](url)
But i also find that its not necessary to use both visual focus and automatic focus at the same time.
What do you think?

jbrazio, 2019-05-20:
@Ultimaboot actually that's a good idea but in order for it to function properly I need to assign a hardware interrupt pin to the Serial RX, none is available right now but the board can be rerouted.

I was also thinking about power, the 5V rail is getting over crowded for the little LDO on the Nano board, maybe the headers should break-out +12V and then the module board has it's own on-board 5V LDO.

But first I think we need to close this ticket which means a wired hand controller for Ardufocus.

Ultimaboot, 2019-05-23:
Oke, for your information i can not close this issue.

jkoenig72, 2019-06-17:
Hi,

Same issue. Want to control the Focuser with 2.

How can I add this functionality to the existing sketch?

Thanks!
Joerg

jkoenig72, 2019-06-21:
I started a bit on this -

for ardufocus.cpp added: 2 ditital pins, 2 and 3 to get buttons movement detected:

...

for(;;)
  {

    int button1State = digitalRead(2);
    int button2State = digitalRead(3);
    int sensorValue = analogRead(A2);
    uint32_t motorspeed = map(sensorValue, 0, 1023, 1, 255);

    comms.receive(button1State, button2State, 125 , 125);

 }

  // Someone made an Opsie !
  // Code should not reach this
  return 0;
}

....

I added a few parameters to the comms.receive function, state of both buttons and the value from a potentiometer.

Within the moonlite.h I then parse those values through:

...

void receive(int forward, int backward, uint32_t motorspeed, int moving)
    {

      char str[CMD_MAX_LEN];

      if(serial::receive(str)) { parse(str, forward, backward, motorspeed, moving); }

    }
...
 and in the parse function, I handle the input, change motor position.

void parse(char* const str, int forward, int backward, uint32_t motorspeed, int moving)
    {
...
if (forward == 1)
      {
        digitalWrite(4, 1);
        uint32_t pos = motor_get_position(motor);
        uint32_t old_motorspeed = motor_get_speed(motor);

        /*if (difference < 500)
          pos = pos + 5;
        */
        pos = pos - moving;
        motor_set_target(motor, pos);
        motor_set_speed(motor, motorspeed);
        motor_start(motor);
        while (motor_is_moving(motor))
          true;
        motor_set_speed(motor, old_motorspeed);

        oldtime = curtime;
      }
      else
        digitalWrite(4, 0);

      if (backward == 1)
      {
        digitalWrite(5, 1);
        uint32_t pos = motor_get_position(motor);
        uint32_t old_motorspeed = motor_get_speed(motor);

       /* if (difference < 500)
          pos = pos + 5;
        else
          pos = 0;
         */
        pos = pos + moving;
        motor_set_target(motor, pos);
        motor_set_speed(motor, motorspeed);
        motor_start(motor);
        while (motor_is_moving(motor))
          true;
        motor_set_speed(motor, old_motorspeed);

        oldtime = curtime;
      }
      else
        digitalWrite(5, 0);
...

ditital pin 4 and 5 are for LEDS, showing the direction.

jkoenig72, 2019-06-21:
The analog input is not working but with fixed values, it seems to work.

Any idea how I can add another analog input working?

jbrazio, 2019-06-21:
Hi @jkoenig72 thanks for your interest on this topic !
I understand that you want to have two buttons (back and fwd) and one pot to define the speed of movement.

I have a few comments:
1) I do agree with the reading of the buttons on the main loop while
2) I would prefer to create a new class to handle the user interface, using the serial port class too handle UI works but it's not the best approach. Nevermind the class thing as refactoring can always be done at the end.
3) You should use `IO::write(pin, state)` instead of `digitalWrite()`
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
jbrazio, 2019-06-23:
Hi @jkoenig72
I've uploaded a new branch (https://github.com/jbrazio/ardufocus/tree/ui/buttons-pot) for you to test.
Check the `config.h` and at the end edit the settings to match your board layout.

Forward, backward and potentiometer speed set is fully functional.

jkoenig72, 2019-06-23:
Thanks - will give it a try tonight...

jkoenig72, 2019-06-23:
Did a quick test ... those setting below works very nice to me, however when I use it in combination with moonlite controller program  ("Moonlite Single Focuser"), I detect that the serial communication breaks after a few seconds a button is pressed (the button in the controller Windows in the lower left corner shows "Connect" again, coming from "Disconnect").

Seems somehow the serial communication gets disrupted.

// NEMA17 motors allow you to use higher speed limits:
//  - Max speed: 1000
//  - Min speed: 250
//
#define MOTOR1_MAX_SPEED 1000
#define MOTOR1_MIN_SPEED  250

// ----------------------------------------------------------------------------
// USER INTERFACE -------------------------------------------------------------
// ----------------------------------------------------------------------------

// Keys and Pot user interface
#define USE_UI_KAP

#define UI_KAP_FWD_BUTTON_PIN 2
#define UI_KAP_BWD_BUTTON_PIN 3

// Switches are designed to be pulled-up HIGH when released and LOW when being
// pushed, this directive allows you to invert this logic.
#define UI_KAP_INVERT_BUTTON_LOGIC

#define UI_KAP_FWD_BUTTON_LED_PIN 4
#define UI_KAP_BWD_BUTTON_LED_PIN 5

// Pin A0 is channel 0 (..) pin A3 is channel 3
#define UI_KAP_ADC_CHANNEL 2

...

jkoenig72, 2019-06-23:
It happens if I press one of the buttons ~ >5 sec.

jbrazio, 2019-06-23:
With my prototype is working, I have no disconnects.
I see you activated the inverted button logic, how are you wiring your buttons ?
When you press the buttons do you see the controller program updating the position counter ?

jkoenig72, 2019-06-24:
Nothing special. 10k pulldown resistors for both buttons, connected to ground. When pressed 5v goes into D2 / D3.

digitalRead returns 0 and if pressed 1 - maybe it's the cable, I will try a few and will report back.

And yes - I can see the counter changing.

jbrazio, 2019-06-24:
Other possible cause could be brownout of the AVR, which means that the 5V rail has not enough power and "restarts" the AVR.

jbrazio, 2019-06-25:
New commit ccae67b84ea8398f34636ced0a1fe7d7187526d1

jbrazio, 2019-06-25:
@opossome @Ultimaboot would you like to test this new feature ?

jkoenig72, 2019-06-25:
Sure. I already build a nice little test board.

I switched the motor driver and now no more serial comm errors.

Sadly I have to travel for a few days. Will do more testing on Friday but great job so far.

jkoenig72, 2019-06-25:
Anything specific you want me to do / test?

Ultimaboot, 2019-06-25:
Well i have to make the hardware first before i can test it, but yes i would too test this new feature.

Ultimaboot, 2019-06-25:
Well i have to make the hardware first before i can test it, but yes i would like to test this new feature.

jbrazio, 2019-06-26:
Thanks everyone, if you find any issues please open a new ticket.
I will merge this branch into the master.

holacomostas, 2019-07-20:
@jkoenig72
I'm sorry, but I couldn't find a way to send you an email.
Would you be so kind as to tell me where I can find the file of the focuser motor bracket that you have in the photos you have sent? Thank you in advance.

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

Email:anofeles@outlook.com

Pd. Very, very sorry for this off topic, jbrazio.

jkoenig72, 2021-05-23:
I have it somewhere in tinkercad. If you still need I can share, but I guess is very easy to do yours elf so it exactly fits your needs. Look up nema holder or similar on thingiverse. Upload in tinkercad and apply your changes...

But let me know if you still need it - I can share.

max2206, 2022-02-25:
> It happens if I press one of the buttons ~ >5 sec.

I have the same problem before i added the buttons al was working wel.

max2206, 2022-02-25:
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

Any idea where we can buy teh latest PCB with the buttons

/\/\arnix

Closed 2019-06-26.

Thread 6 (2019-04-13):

28byj-48 mod wiring

djibb, 2019-04-13:
Hi,

It's difficult for me to know which wire is where... all is A/B Black and Red...

here for example : https://github.com/jbrazio/ardufocus/blob/master/doc/wiki/schematic-bipolar_bb.png
Which is the right wiring with colors ?
pink orange yellow, blue ?

Orange near 12V ? 5V ?

Tks a lot... I heard some n,oise but don't know if my morotr is down or ma A4998 is down... or my wiring is down...

:) tks for help a noob.

jbrazio, 2019-04-13:
Well wire colours vary per supplier, usually there is some trial and error when you don´t know the motor phases. You may get a DMM and measure the resistance between each pair of wires, if they are on the same coil then you´ll get a reading, otherwise it will show open circuit. After knowing which pair belongs to each coil is just  a question of choose one coil to be A and the other to be B.

Just keep in mind to cut all the power to the Arduino (USB cable) and the step stick BEFORE unplug any motor wires.. not doing so will fry the step stick micro.

If your motor does a humming noise and does not move then for sure is the coils in the wrong place.

Here is a table with common wiring schemas.. but yours may be different !

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

jbrazio, 2019-04-13:
@djibb are you using a Nema 17 or a modded 28byj-48 ?

Portia-Lin, 2022-07-05:
@jbrazio You have not specified the contacts of the windings quite correctly. The place where the contacts of the windings are soldered to the board should have the following designations: A1 B1 X A2 B2. So:
Yellow: A1
Blue: A2
(or numbered in reverse)
Orange: B1
Pink: B2
(or numbered in reverse)

Closed 2019-05-12.

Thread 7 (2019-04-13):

wiring/config.ino

djibb, 2019-04-13:
Hi,

in config.ino, line 104 :
  #define MOTOR1_PINOUT  12,  11,  10,     8,     7,   6

in schematics :
https://github.com/jbrazio/ardufocus/blob/master/doc/wiki/schematic-bipolar_bb.png

there's no 6 but 9 pin...

Any hint ?

djibb, 2019-04-13:
OK. got it. I've wired as explain in INO file. working great -> thanks

jbrazio, 2019-04-13:
Glad you sorted it out, I'm closing this, reopen if needed.

Closed 2019-04-13.

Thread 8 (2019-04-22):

PCB components missing from BOM

Ultimaboot, 2019-04-22:
Hello,

You did a great job with the Ardufocus, thanks.

I have a question about your PCB.
What means the 100nF and 10K unter the Arduino Nano board.
100nF is not a part of the components.
Are this components on the top side or bottom side of the PCB?

And what is the purpose of the NTC component?

Please could you explain it to my?

With Regards

Peter Boot

jbrazio, 2019-04-22:
Hi Peter,

When I get time I need to do a better documentation about the project.. I do understand that people have to dig a bit to find everything. Thanks for pointing that out, indeed the BOM is out of spec in relation with the PCB design.

The 10K resistor is part of the NTC logic and it's needed to act as a voltage divider, it is listed in the BOM as "1x Resistor 1/4W 10K". This resistor should be measured before being soldered into place and the value of NTC_RESISTOR_VAL set to the exact measurement, this will make the NTC to report more accurate data.

The 100nF cap is decoupling cap added on the latest version of the PCB and this is the reason it's not on the BOM.

All components on this PCB are mounted on the top side and soldered on the bottom with the exception of these two you pointed out, as they are SMD they are also soldered on the top surface.
I had past requests to make this a DIP only board meaning all SMD should be removed and replaced with trough hole ones this is somewhere on the pipeline but I've been busy getting the ASCOM driver and dual-motor support working.

The current PCB version is also lacking new functionality such as `ENABLE_DTR_RESET` which will disable/enable the RESET hold capacitor by a serial command thus allowing USB firmware upgrade without removing the Nano from the PCB.

Ultimaboot, 2019-04-23:
Thanks for the quick replay.
The preforated Board is than also not up to date?
Is there now a new version of the PCB available?
If not than i have to remove the Nano from the PCB, upgrade the software and than put it back to the PCB, correct? Could i use a PCB arduino nano socket strip to overcome this problem for this moment?

jbrazio, 2019-04-23:
Both are out of date in relation with the DTR reset.

You can use a socket and remove the nano for programming or with a bit of practice you can press the reset button at a specific time when uploading from the IDE/PlatformIO and it will proceed.

Ultimaboot, 2019-04-23:
Last question for now:)
what voltage is needed for the 100nF component, 50V?

jbrazio, 2019-04-23:
The voltage on that rail will be 5V, so anything above 10V will work.

BTW, if you are building the prefboard version it's easy to enable the DTR function, just connect the GND leg of the 10uF cap to pin A5 of the Nano and then set the `DTR_RESET_PINOUT` to 15, you also need to enable `ENABLE_DTR_RESET`.

Ultimaboot, 2019-04-24:
Thanks for the reply and tips.

Ultimaboot, 2019-04-24:
Thanks for the reply and tips.

Ultimaboot, 2019-04-24:
What is the PRGM on the right upper corner?

jbrazio, 2019-04-25:
That’s the old method to enable the automatic reset for firmware upload. If you cut the trace then the reset will be enabled, put a solder blob and it’s locked again.

This auto reset is a big thing when using the Moonlite ASCOM driver, it will fail to connect to the focuser. With my new drivers it is irrelevant.

Ultimaboot, 2019-04-25:
If i want to use your PCB i only have to put all the components in the BOM and the one we spoke of in the mail before/above and connect with a piece of wiring the GND leg of the 10uF cap to pin A5 of the Nano.
Do i have to cut the trace (PRGM) yes or no? With this question answered i think this will work, correct?.
Setting the DTR_RESET_PINOUT to 15 is a software adjustment, correct?
Enable ENABLE_DTR_RESET, is this cutting the trace (PRGM) or is this also a software adjustment?

jbrazio, 2019-04-26:
If you want to use the PCB as is you have all the components spaces there so it will be OK.

If you want to use the DTR feature with that PCB you will need to cut the trace on the PGRM jumper and solder a wire between the left side and pin A1 (Example) then activate on the firmware config.h the feature and the Pin you selected.

But.. this feature is yet experimental and it will be there for Moonlite driver compatibility only.

My advice is: solder some female headers on the PCB and pop up the nano if you want to upgrade the firmware. To make it easy to remove the nano, populate only the nano board with the required male header pins, leaving all the other (non used) pins bank. If you are unsure which ones should be populated I can give you a list. This will make a lot easier to pop up the nano board from the PCB.

Ultimaboot, 2019-04-26:
In the mail of 25-4 your mention connecting to pin A5 of the Nano board and now it is pin A1 of the Nano Board. Is it pin A5 or A1?
a list would also be helpful, thanks.

jbrazio, 2019-04-26:
It’s just an example you may use A1 or A2 or any other one available.

A0 is pin 14 (used by NTC)
A1 is pin 15
(...)
A5 is pin 19

Closed 2019-05-12.

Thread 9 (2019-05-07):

Pro Micro 32U4 support possible?

kyuzumaki, 2019-05-07:
Would it be possible to support the Arduino Pro micro?

I tried adding it to the list of boards but the registers seem to be different. Is there an easy fix for this or is it a limitation of the chip?

```
Board: "SparkFun Pro Micro, ATmega32U4 (3.3V, 8 MHz)"
serial.h:50: error: 'UCSR0A' was not declared in this scope
         UCSR0A &= ~bit(U2X0); // baud doubler off
```

jbrazio, 2019-05-07:
The ATmega32U4 was not on the supported list of microcontrollers; I don't have any on hand but I'll update the HAL and you'll do the validation.

jbrazio, 2019-05-07:
Are you positive your board is the 3.3V at 8MHz and not the 5V at 16MHz ?

If it is the 3.3V version there are some things to consider:
- Timers should be OK as they are calculated based on `F_CPU`
- NTC will work as it is VCC independent.
- 3.3V logic may have issues with the step stick drivers which are 5V logic.

jbrazio, 2019-05-08:
@kyuzumaki Do you mind to test ?
Download the tarball from [here](https://github.com/jbrazio/ardufocus/archive/hal/atmega32u4.zip), uncompress, configure and upload.

Pay attention to the weird numbering on the pins..
`A0 is 18`, `A1 is 19`, `A2 is 20` and `A3 is 21`.

kyuzumaki, 2019-05-08:
Tried with CoolTerm but the com port just dosen't show up at all.

I tried to add in some Serial.println("DEBUG INFO") lines into the code to see where it jams but the command is not recognised. I'm guessing that the default serial driver is different somehow from what the Nano uses. The [sparkfun pack](https://cdn.sparkfun.com/assets/learn_tutorials/1/2/1/SparkFunBoard_Addons_Jan_16.zip) has a few Hardware_Serial.h files in there but haven't figured out whats different.

jbrazio, 2019-05-08:
You didn't answer to my question, do you have the cap between GND and RST ?
Maybe it needs special initialization, I'll check how the Sparkfun variant is handling the serial port.

`Serial()` is not available because I'm not using the Arduino framework. Try the following, get and LED with proper resistor on `PIN A3` then edit `ardufocus.cpp` and at the end of the `DEBUG` section after the `#endif` add `DDRF = bit(PF4)` then you can toggle the LED using `PORTF ^= bit(PF4);`

Validate first with a blank sketch that the LED is working:
```C++
void setup() {
  DDRF = bit(PF4); // Set A3 as OUTPUT
}

void loop() {
  PORTF ^= bit(PF4); // LED ON
  delay(1000);
  PORTF ^= bit(PF4); // LED OFF
  delay(4000);
}
```

jbrazio, 2019-05-09:
I've been digging into the Arduino core source code and this will be a bit harder than I initially thought, at a first glance all the USB "core" subsystem needs to be implemented so the Serial can work..

So the device has two serials, one is the USART1 and the other is the USB based one. The changeset I've build targets the internal USART1, so the serial which is available at pins `TX0` and RX1` which will need a USB-to-TTL converter in order to be used. :disappointed:

@kyuzumaki If you have a FTDI USB-Serial 3.3V dongle can you confirm that the USART1 is working ?

kyuzumaki, 2019-05-09:
Sounds like this is a more complex problem than I had thought initially! I’ve just ordered an Arduino Nano since it has the separate serial chip and works already.

I do have an FTDI serial board but it’s not with me at the moment. I can test the second serial port it in a few weeks when I’m back at my workshop but I’m starting to think it may not be worth adding support for the chip unless there is more demand for it.

In answer to your question about the  capacitor I don’t have any 10uF caps to try the largest I have at hand is 100nF not sure if that’s big enough to work?

jbrazio, 2019-05-09:
If you don't mind validating the USART1 when possible I would appreciate it and would keep the HAL supporting that bit, at least what was done is kept. Full USB Serial support is another story for now.

100nF should work also.

kyuzumaki, 2019-05-10:
Have tested using USART1 connection and it works. Was able to connect it to kstars and control the 28byj stepper motor.

jbrazio, 2019-05-11:
Thanks for the time taken to validate the PR #10 at least not everything is lost.

Closed 2019-05-11.

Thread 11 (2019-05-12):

Modified step motor 28BYJ-48 with PCB not working

Ultimaboot, 2019-05-12:
Hey,
I finally succeeded in assembling the PCB. I soldered the components on the PCB, and put the code in the Arduino Nano.
Put 12V power supply on PCB and the PWR LED lights up green. The usb connected to the laptop. Arduino Nano is found by the laptop on COM 6. When I connect to the software, the DX and RX Led start blinking at the same time. When I try to control the motor, the flashing speed of the DX and RX LED changes briefly and then returns to the original speed. The step motor does not move at all. The step motor is a modified 28BYJ-48 and is connected according to issues 2 of this site. The step motor also gets hot. Can you give a clue as to what I can do?

jbrazio, 2019-05-12:
Hi @Ultimaboot !

Try to first check if the firmware is OK, just open Teraterm or miniterm session (9600bps, 8-bit, no parity, 1 stop bit) and you should be greeted with a welcome message, if not try to press the `reset` button on the Nano while being connected to the serial port.

If the motor gets hot usually there is and issue with the motor windings. There has been a lot of confusion due to the messing naming schema (1A, 2A, 1B, 2B). I have not corrected [this post](https://github.com/jbrazio/ardufocus/issues/6#issuecomment-482882163) and published a [new guide about modding the motor](https://ardufocus.com/docs/28byj-48-bipolar-hw-mod/#modding-the-motor). Please read it and double check your connections.

Ultimaboot, 2019-05-12:
Connecting with tera term gives me the following message:

```
 Ardufocus 0.2b-master ready.
                            Visit https://github.com/jbrazio/ardufocus for updates.
```

jbrazio, 2019-05-12:
Then the firmware is OK.

jbrazio, 2019-05-12:
That's a good sign, the firmware should be OK.
Did you had time to check the motor windings ?

Ultimaboot, 2019-05-12:
The motor windings are correct.
Orange connected to pin 1A A4988;
Pink connected to pin 1B A4988;
Yellow connected to pin 2A A4988;
Blue connected to pin 2B A4988.
Red not used and middle trace step motor by scrapping the PCB varnish and copper.

jbrazio, 2019-05-12:
Could you post your `#define MOTOR1_PINOUT` from `config.h` ?

Ultimaboot, 2019-05-12:
#ifdef MOTOR1_USE_A4988_DRIVER
  //                                       MS1, MS2, MS3, SLEEP,  STEP, DIR
  #define MOTOR1_PINOUT  12,   11,    10,      8,         7,      6
#endif

jbrazio, 2019-05-12:
Are you using the PCB version or the prefboard one ?

Ultimaboot, 2019-05-12:
PCB version

jbrazio, 2019-05-12:
To use `OUT1` on the silkscreen do `#define MOTOR1_PINOUT 16, 6, 5, 4, 3, 2`to use `OUT2` do `#define MOTOR1_PINOUT 12, 11, 10, 9, 8, 7`.

Ultimaboot, 2019-05-12:
Its not working.

jbrazio, 2019-05-12:
Do you care to take a overview picture from the top side of the board with everything connected ?

Ultimaboot, 2019-05-12:
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

jbrazio, 2019-05-12:
Everything looks OK. I assume that 2nd wire is orange one and not the red one, on my motor orange's color tone is yellowish rather than reddish as yours.

Did you adjust the pot on the step stick ?
Do you see the flat lip on the pot ? Try rotating it 180º CW.

Ultimaboot, 2019-05-12:
Yes I did try to adjust the pot on the step stick CW and CCW but that didn't work.

jbrazio, 2019-05-12:
Do you hear or feel any vibration from the motor when it was supposed to be running ?
Which software are you using to test the motor ?

Ultimaboot, 2019-05-12:
I do not hear or feel any vibration from the motor.
I use MoonliteSingleFocuser_v1.4 to test the motor.

jbrazio, 2019-05-12:
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

- Test continuity between the top pins in purple and the Arduino pins.
- Test continuity between the bottom coil pins and the motor wires.

- Measure resistance between "1B 1A" and "2A 2B", which values do you have ?

- Measure voltage between RST and GND you should have +5V
- Measure voltage between ENA and GND you should have 0V
- Measure voltage between bottom two first pins, you should have +5V
- Measure voltage between bottom two last pins, you should have +12V

- Is the NTC connected between 1 and 2 or 2 and 3 and not between 1 and 3 ?

jbrazio, 2019-05-12:
Could you please also post your entire `config.h` ?

Ultimaboot, 2019-05-13:
Test continuity between the top pins in purple and the Arduino pins. This is correct.

Test continuity between the bottom coil pins and the motor wires. This is correct.

Test continuity between ENA and GND you should have it. This is correct.

Measure resistance between "1B 1A" and "2A 2B", which values do you have ?
1B (Pink) 1A (Orange) = 203 ohm and 2A (Yellow) 2B (Blue) = 201 ohm. This a 12V step motor nr 181228766

Measure voltage between RST and GND you should have +5V. This is correct

Measure voltage between bottom two first pins, you should have +5V. This is correct

Measure voltage between bottom two last pins, you should have +12V. This is correct

Is the NTC connected between 1 and 2 or 2 and 3 and not between 1 and 3 ? 1 and 2 (left and middle on picture)

Config.h (ZIP file)
[config.zip](https://github.com/jbrazio/ardufocus/files/3174117/config.zip)

jbrazio, 2019-05-13:
The config file looks OK also.
All tests check out.

Can you test continuity between M1B and all others ?
Can you test continuity between M1A and all others ?
Can you test continuity between M2A and all others ?
Can you test continuity between M2B and all others ?
Can you test continuity between the two parts of the cut trace on the motor ?

If all this checks validated then I must start thinking about a broken step stick.
Do you have special tools such as a logic analyser or an oscilloscope ?

Ultimaboot, 2019-05-14:
Can you test continuity between M1B and all others ? This is correct.
Can you test continuity between M1A and all others ? This is correct.
Can you test continuity between M2A and all others ? This is correct.
Can you test continuity between M2B and all others ? This is Correct.
Can you test continuity between the two parts of the cut trace on the motor ? This correct.

Can you test continuity between any ground pin on the arduino and the first bottom left pin on the step stick ? (This is the ground pin of the +5V on the step stick). This is correct.
Test again between GND on arduino and the 7th pin on the step stick (This is the +12V ground). Both should have continuity. This correct.

Do you have special tools such as a logic analyser or an oscilloscope ? I have no special tools.

If all this checks validated then I must start thinking about a broken step stick. Well i was smart to buy some spare parts. When i Exchange the step stick nothing happened but i did hear some noise from the step motor, so i turned the pot and now it is working. So try it again with old step stick and nothing happened. The step stick was indeed broken. Is there a ideal setting for the pot?

jbrazio, 2019-05-14:
Great news !

These step sticks are very susceptible to burn out if we accidentally, or not, disconnect one of the four motor coils with it having +12V power.. it will instantly burn out internally.

There is a trick to correctly set the pot to your motor power requirements, so you have a 200R per coil motor at 12V this gives us 0.06A, let’s round it to 0.1A.

Use the following formula:

Vref = 0.1 * 8 * 0.1 <=> Vref = 0.08V

Take a multimeter and measure the positive on the center of the pot against any GND point on the board. You should set this to the Vref value above.

**Attention this is assuming that the little SMD resistor near the pot is a 0.1R one.**

Could you please check the number written on it ?

Ultimaboot, 2019-05-15:
The Resistor on the A4988 is R100 what is 0.1ohm.
Vref = 0.1 * 8 * 0.1 <=> Vref = 0.08V.
The setting of the pot is now 0.08V.
Everything is still running.
Next step 3D printing
I will close this issue.

Closed 2019-05-15.

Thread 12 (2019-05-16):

compile error - error: no matching function for call to 'uln2003::pinout_t::pinout_t(<brace-enclosed initializer list>)'

jrhilton, 2019-05-16:
Hi, i've downloaded the files and simply opened ardufocus.ino and configured for ULN2003 per the readme. When trying to compile it comes up with the following error (using Arduino IDE 1.6.9).

What am I doing wrong?

ERROR:

In file included from sketch\motordrv.h:31:0,

                 from sketch\ardufocus.h:30,

                 from sketch\ardufocus.cpp:20:

sketch\uln2003.h: In constructor 'uln2003::uln2003(const uln2003::pinout_t&)':

uln2003.h:56: error: no matching function for call to 'uln2003::pinout_t::pinout_t(<brace-enclosed initializer list>)'

     inline uln2003(pinout_t const& pinout) : m_pinout({ pinout }) { ; }

                                                                 ^

sketch\uln2003.h:56:65: note: candidates are:

sketch\uln2003.h:32:12: note: uln2003::pinout_t::pinout_t()

     struct pinout_t

            ^

sketch\uln2003.h:32:12: note:   candidate expects 0 arguments, 1 provided

sketch\uln2003.h:32:12: note: constexpr uln2003::pinout_t::pinout_t(const uln2003::pinout_t&)

sketch\uln2003.h:32:12: note:   no known conversion for argument 1 from '<brace-enclosed initializer list>' to 'const uln2003::pinout_t&'

sketch\uln2003.h:32:12: note: constexpr uln2003::pinout_t::pinout_t(uln2003::pinout_t&&)

sketch\uln2003.h:32:12: note:   no known conversion for argument 1 from '<brace-enclosed initializer list>' to 'uln2003::pinout_t&&'

exit status 1
no matching function for call to 'uln2003::pinout_t::pinout_t(<brace-enclosed initializer list>)'

jbrazio, 2019-05-17:
Hi @jrhilton,

I've just tried to compile with IDE 1.8.5 and was successful using `#define MOTOR1_USE_ULN2003_DRIVER`:
```
Sketch uses 10608 bytes (36%) of program storage space. Maximum is 28672 bytes.
Global variables use 512 bytes (20%) of dynamic memory, leaving 2048 bytes for local variables. Maximum is 2560 bytes.
```

Could you attach your `config.h` file ?

jrhilton, 2019-05-17:
Hi there, I think the error is at my end, I tried compiling on another laptop with the latest version of the IDE and it worked without an issue. I suspect something is wrong with the older install. This can therefor be closed as solved. Many thanks for the prompt reply, sorry I seem to have wasted your time.

Closed 2019-05-17.

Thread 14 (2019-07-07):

Moonlite Compatibility

bbillp, 2019-07-07:
How Is the Adufocus controller connected to the Stand alone Moonlite Hi-Rez Stepper motor DB9 connector ?  I don’t see circuits for the DB9 connections.   Thank you .....

jbrazio, 2019-07-08:
Hi !
Have a look at the INDI documentation for the Moonlite Protocol [here](http://indilib.org/media/kunena/attachments/1/HighResSteppermotor107.pdf).

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

To connect to Ardufocus you need to use the ULN2003 driver because the Moonlite motor is a unipolar one, have a look [here](https://ardufocus.com/manual/build-instructions/#motor-connections).

bbillp, 2019-07-08:
Thank you for this information, So the Moonlite Motor assembly DB9 goes direct to the Stepper motor so I understand there is NO electronics interface in the Moonlite motor box, only the stepper.  Now the project makes sense to me.

I want to use the Moonlite Motor because it has some very nice mechanical features.

Do I use the Arduino IDE to load your code ?

Will you include a LCD display for Stepper Position like the PNP_Focus project ?

Are you in Portugal, I love the country and drove my car from Faro, Salame in the South thru Lisboa, Porto, Nazare, Obidos and north, very very nice ....

Thank you  ..... Bill P. In Huntington Beach, California USA

Sent from my iPad

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

jbrazio, 2019-07-08:
Hi BIll,

Before going into expensive motors give a try to a cheaper solution.. you may be surprised. ;-)
I've been using a prototype focusing mechanism with my TS MonorailR96, even when using single stepping on the driver it can archive sub micron movement (0.195 micron) for each step or in other words the resolution is around 5 step/micron.

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

If there is demand for the LCD we can work it out.

Yes I'm indeed from this little paradise named Portugal. :-)
Did you had the opportunity to stay a night in Alentejo ? There's were we have the best starry nights.

bbillp, 2019-07-09:
Yes I agree on a simple solution like your drawing but the end of the lead screw must not interfere with the diagonal or the camera.  The focuser need not have a long travel as focus will be preset by eye then use the focuser to ‘fine tune’ the image. My drawing shows an idea to use a push rod and a lever to turn the focus knob a few degrees for fine tuning.  The push rod can be motivated by one of 3:  Stepper, linear actuator or RC airplane servo which is very cheap.

Is Ardufocus code loaded with the Arduino IDE?  I have not studied the code today.

I made a small linear actuator using a 3mm threaded rod and modified RC servo motor and searched the internet for a NEMA-8 or smaller stepper last night, some micro steppers are only $2.00, amazing.  Old PC printers and scanners are very good sources for these parts and there are many of these things in the trash so I have a treasure box of small motors and will use the DRV8825 in my final version IF necessary.

I believe the Focuser can control any one of the motors except the servo, maybe .... as you know the RC servos operate by frequency and PWM modulation, simple 5 volt one wire signal + power supply 5V.

It should not be too difficult to load PNP_Focus LCD code into Ardufocus, I will try it after loading Ardufocus but I thought your code included LCD, its been a long day and no time to study.   I feel a LCD with counter readout is very necessary when using a manual controller.  A photo of PNP_Focus is below.

We often visit Madrid Spain then drive somewhere.  During the 90s we drove to Cadiz then east to Faro, Lagos and when I got tired of driving I found a little road to the beach, Salame, wonderful ! We had a room right on the beach for two nights.  Over the next 6 nights we worked our way up the coastal route (Portugal is very similar to Southern California) staying in Nazare, Lisboa, Porto, Obidos then north to Santiago de Compostella Spain.  We saw the beautiful castles in Cintra and Pena (?) and ate LOTS of seafood.  My son returned numerous times to Portugal near the Spanish border for short holidays.  We have wonderful memories of our trip and before I get too old I want to return.

Siesta time, I look forward to hear from you ..... Bill

PNP_Focus Arduino

Sent from my iPad

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

jbrazio, 2019-07-09:
Your message didn't had any attachments.

Indeed, I can get away with such a rod in that position because I have a thin-long imaging train: Reducer - OAG - FW - CCD

Yes it should compile with the Arduino IDE but the code itself is not "arduino" based, so libs that are made for Arduino will not work with Ardufocus without some knowledge.

bbillp, 2019-07-09:
Hello Joao, I don’t know why the attachments disappeared but here they are again.    Bill

Astrotech AT80edt with focus lever drawing with push rod by servo or linear actuator.

Home made Mini Linear Actuator

PNP_Focus readout.

Sent from my iPad

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

jbrazio, 2019-07-09:
You’re using the email to reply to the thread, I don’t think they will work like that, tru using the github web page instead.

Closed 2019-07-31.

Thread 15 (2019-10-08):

Can't get the motor to work

pardovot, 2019-10-08:
I'm not sure this is the correct place to ask for assistance, but I didn't saw any contact form, forum, or any other place to get it, I also don't actually know if the issue is code related. If there is another appropriate place for that, please let me know so I won't waste your time.

So my issue is as follows:
I've connected the ULN2003 + 28BYJ-48 + Adruino nano as showed in the diagrams(except I didn't use resistors, capacitors etc yet and used 5V instead of 12V), then uploaded the arduino code and started up moonlite, I managed to connect to it and "perform a few actions" as you can see below:
image.png
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

Yet nothing happens, the leds in the ULN2003 doesn't turn on, and the motor doesn't move at all. When connecting the arduino to the PC the ULN2003 leds blink for a few seconds.

I used a sample code to rotate the motor and everything worked just fine.

I have another friend that connected everything as should in the diagram including resistors, capacitors, and with 12V, and he still had the same issue as I have.

Is there anything we're missing?

Thanks a lot!

Closed 2019-10-09.

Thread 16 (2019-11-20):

Arduino IDE

jyecker, 2019-11-20:
I'm a little confused about how to build a sketch from your files. All I see are library files. I don't see a main program loop.
Thanks for your effort. It looks like your project has all the features I need. I just need to figure out how to upload a sketch to an Arduino Nano. I'll be using a unipolar motor and I see how to implement that in the config file so I understand some of what's happening.
Again thanks.

jyecker, 2019-11-21:
I figured it out.
Thanks

Closed 2019-11-21.

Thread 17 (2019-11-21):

Motor wont turn

Shastarocks, 2019-11-21:
I have the Nema 17 motor with a A4988 motor controller running off an arduino nano. I cant seem to get the motor to turn. I wired it exactly as [in this diagram](https://stargazerslounge.com/uploads/monthly_2017_07/schematic-bipolar_bb.thumb.jpg.eacc4dea5e85822bc6e35beb76ada258.jpg).

jbrazio, 2019-11-22:
Hi ! Please try the updated version of the diagram at the [official build instructions](https://ardufocus.com/manual/build-instructions/).

Closed 2019-12-14.

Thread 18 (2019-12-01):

Sometimes focuser goes to 0 absolute, instead of step out or step in command.

jedas, 2019-12-01:
Quite often, like 5% of the time, focuser goes to 0 absolute position instead of making small step. Using Ekos/Indilib on virtual machine. Arduino mini. Can't be sure that it's not a driver's issue.
Kind of 'solved' by checking target distance, if it's >1000, don't move in function stepper::set_target_position.

jyecker, 2019-12-17:
I have almost the same problem. It does't go to 0 but will go to a low absolute value. Something like 26, 48,or 228.  It doesn't matter whether it's a small in or out move that's commanded.  It behaves the same with Moonlite ASCOM or Ardufocus ASCOM or the Ardufocus Handpad app. It will not stay connected to the Moonlite Windows app. It usually disconnects after  GT# but not right away. I'm using a Mini Pro so I don't have an NTC hooked up (no AREF pin) but I tried it on a Nano with an NTC temp sensor and I get the same results. It just seems random. Checking off the Trace box the commands from the the computer seem OK.

jedas, 2019-12-18:
I had a few imaging sessions with firmware which limits it to 1000 steps max. Sometimes focusing fails, but it never jumps so far into back focus (low values), thus it's way easier to work and it's more stable. Not using NTC either.

jbrazio, 2020-01-08:
First of all sorry for the late reply.
@jedas @jyecker Are you using ASCOM with my driver or the Moonlite one ?

>  It will not stay connected to the Moonlite Windows app. It usually disconnects after GT# but not right away.

This is usually due the arduino auto reset feature, did you install the capacitor between GND and the RST pin ?

jedas, 2020-01-08:
I'm using Indilib (EKOS) on VM Ubuntu on Windows 10. FTDI virtual serial port for USB-TTL connection and arduino mini.

jbrazio, 2020-01-08:
> Quite often, like 5% of the time, focuser goes to 0 absolute position instead of making small step. Using Ekos/Indilib on virtual machine. Arduino mini. Can't be sure that it's not a driver's issue.
> Kind of 'solved' by checking target distance, if it's >1000, don't move in function stepper::set_target_position.

But this is not a solution.. target distances can be a lot bigger than 1k step.
Do you have an option on EKOS to log the serial communication with the focuser ?

I see that @jyecker has a different setup from yours, he is using ASCOM and you INDILIB.. so we may be looking at a true bug here. May I ask you @jyecker to do the same thing, on the ASCOM settings activate the serial debug and send me a log file where the issue occured ?

jedas, 2020-01-08:
I've enabled debug log check, but I didn't see any communication log there. I'll look for it during next imaging session. I was suspecting, that some command byte is not being recognized correctly, therefore ending up as zero. From time to time, I still see EKOS displaying 0 coordinate, as reported by focuser. But this is being filtered with my hack, focuser doesn't move to that location, so it doesn't corrupt focusing procedure. I understand that it's not good solution to limit to 1k step, but it kind of worked on my setup. I'm looking forward for proper fix. Your firmware is great.

jyecker, 2020-01-08:
Here's my setup. I'm using the ULN2003 motor driver, I have commented out the buttons and the LED's. So about as stripped down as I can get. I'm using a Mini Pro with the FTDI cable. I have not had the cap hooked up and I don't have a temp sensor hooked up either. I did have a Nano with a sensor and a cap hooked up but it responded the same. The Mini Pro will connect with your app, your ASCOM driver and the MoonLite ASCOM driver without any timeout problems. They all have the run away problem. The MoonLite app is the only one with the disconnect issue. You'll see in the log file that after a command to goto 2025 (SN07E9) it ends up at 233.
Here is the log file from ascom.
[ASCOM.MoonLite.1729.497710.txt](https://github.com/jbrazio/ardufocus/files/4037662/ASCOM.MoonLite.1729.497710.txt)

jbrazio, 2020-01-09:
@jyecker Indeed the log clearly shows the erroneous behaviour.

Is this always reproducible ?
Did you do any changes on the codebase other than on the config file by enabling/disabling `#defines` ?

jbrazio, 2020-01-09:
@jyecker do you care to open the ASCOM Diagnostics application and enable on the Trace menu:
- Serial Trace Enabled
- Include Serial Trace Debug Information

Let's see if this gives us more information on the log file.
The file(s) should then be located at `(..)\Documents\ASCOM\Logs XXXX-XX-XX`

jyecker, 2020-01-09:
I think this is what you want, I ran it again this time it took a little longer ( time to fail is random ) but it usually fails within a few minutes or sometimes in a few clicks. I just keep making in or out relative movements.  It's pretty consistent except for the number of commands until it does it.   15:18:12.944 may be the time of interest ?  There are 2 more serial debug files if you need them. I don't think I have any code changed except the config.h.  I used the uln2003 mtr drive, changed the pins to 3,4,5,6 and commented out the UI buttons and LEDS. I do have two inputs floating. The UI_KAP_ADC_CHANNEL 1 and the A0 temp pin. The Mini Pro does not bring the A_REF of the ATMEGA out to a pin.  I did try it with a Nano and two 10k resistors to give it a constant temp but it didn't make a difference. I'm not that interested  having the temp comp. right now, although it would be nice in the future.  I thought that having that pin float might be an issue but the temp seems to be fairly consistent in the log files.
Also the Mini Pro does have a DTR pin on the serial connection, it has RTS instead. I don't know if that makes a difference on the way it is reset by the software. Anyway the cap doesn't seem to make a difference with the ASCOM driver. It doesn't help the MoonLite app either.
I really appreciate you taking the time to look at my issue.
[ASCOM.MoonLite.1514.293870.txt](https://github.com/jbrazio/ardufocus/files/4042568/ASCOM.MoonLite.1514.293870.txt)
[ASCOM.Serial.1514.294040.txt](https://github.com/jbrazio/ardufocus/files/4042572/ASCOM.Serial.1514.294040.txt)

jyecker, 2020-01-10:
Don't spend too much time yet. I took it home and on my home computer I couldn't get it to do it. Let me test on some other computers first before I get you too involved. I've tested a lot of different focuser projects on my work computer so maybe sometime is corrupt. I'll update you on my results.

jbrazio, 2020-01-10:
But we have two different people with the same strange behavior.. I suspect something is there and happens on very special circumstances.

Btw, did you use the Arduino IDE to compile the code ? Can I have which version did you guys used ?

PS: I didn’t had the opportunity to check your latest logs, will do it soonish.

jbrazio, 2020-01-14:
I've checked the logs and I don't see anything to write home about.. :-/
How do you have the FTDI breakout board connected to the Nano, could it be noise on the serial line ?

I will add a special `#define` to disable temperature code block completely, this will remove some ISR/ADC workload and return a constant bogus temperature value.

jyecker, 2020-01-14:
I have two configurations. One is a Pro Mini with an FTDI Cable. Like this one. FTDI Cable 5v The other is a Nano with a CH340 USB to Serial converter on the board. ( Chinese Arduino clone) Not an FTDI but built into the board.It might be helpful to leave out the temp stuff since it 's not going to be easy to do with the Pro Mini without some rework.The behavior is the same with both setups. The USB2-USB3 thing seems not to be the case. I don't know why it seemed to work that one night.Have you had any experience with the cheap Arduino's and do you think that could be the issue?Thanks again for your efforts. John

|
|
|
| $17.95 |  |

 |

 |
|
|  |
FTDI Cable 5V

The FTDI cable is a USB to Serial (TTL level) converter which allows for a simple way to connect TTL interface d...
 |

 |

 |

John

    On Tuesday, January 14, 2020, 02:14:19 PM EST, João Brázio <notifications@github.com> wrote:

I've checked the logs and I don't see anything to write home about.. :-/
How do you have the FTDI breakout board connected to the Nano, could it be noise on the serial line ?

I will add a special #define to disable temperature code block completely, this will remove some ISR/ADC workload and return a constant bogus temperature value.

—
You are receiving this because you were mentioned.
Reply to this email directly, view it on GitHub, or unsubscribe.

jbrazio, 2020-02-07:
@jyecker I use a lot of cheap 1 dollar nanos from Aliexpress and my experience with them is rather positive, in fact both of my focusers are using those cheap arduinos and they work just fine.

I suspect this could be a compiler error. Each Arduino IDE version comes with it's own buildroot, gcc and glibc version.. which means whe can have different binary outputs from the same source code.

Could you please tell me your Arduino IDE version ?
Do you know how to standalone flash a binary to the Arduino using avrdude ? I could compile it using my environment and then check if it behaves the same on your hardware.

jyecker, 2020-02-07:
I'm using Arduino IDE 1.8.10.
I haven't used AVRDUDE before. I looked at a ladyada tutorial and although I think I could do it, It may require some babysitting on your part. You may not wish to do that which I would fully understand. I'm not a coder and rely on the generosity of guys like you for my code which is greatly appreciated.
Just to clarify, this is not reproducible on your end?

Closed 2020-02-29.

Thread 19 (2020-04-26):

A way to specify step size in UI_KAP

ccaramel, 2020-04-26:
Hi,
congratulations for this amazing work!! even I got some issues using Moonlite protocol.

The questions is, I'm currently using UI_KAP function, which is working, but It move step by step at a speed determined by Arduino polling which is very very slow.
Is there a way to interact with this or modify defaults in your code?
Regards.

jbrazio, 2020-05-09:
Hi !
Do you want to specify a "fixed" speed at build time or have a way to change it on-the-fly when using ?

ccaramel, 2020-05-10:
Hi, finally succeeded in setting a fixed value in ui_keybd.cpp then succeded in using a pot to change focus speed. Maybe it could be useful to join a schematic with pot connections.
The only remaining problem is with acceleration during manual focusing, it would be great to be able to set an acceleration profile dedicated to ui_keybd.

Using MoonLite protocol (both with indi and indigo) it regularly shows an absolute position @0 and a temperature @0 for a few seconds then come back to real value. It has the same behavior using various nanov3 or uno. What do you opine about it?
Regards

Closed 2020-06-01.

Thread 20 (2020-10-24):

Speed with the  user interface (switches).

Antiath, 2020-10-24:
I would like to change the speed in manual mode. Righ now, the acceleration is very slow and the top speed achieved is also quite low. It is fine though when I'm controlling the device with the ascom driver ( the firmware is set to 400 steps/sec maximum in the config file). Wich part of the code do I have to change to resolve this ?
Also, is this manual mode using half steps ou full steps by default ?

Antiath, 2020-10-24:
Well never mind. I figured out what that #define UI_KAP_ADC_CHANNEL line was for :p Now I just need to add a pot to ro the remote.
As a side note, it woul be nice to document that speed control feature. The config.h file doesn't give much info about that. It doesn't even state the possibility to control the speed of the user interface.

dwilbourn618, 2022-01-17:
Antiath, It's nice that you worked out what the  #define UI_KAP_ADC_CHANNEL line was for, but not all of us are as smart as you! Can you explain a little about what this does and how I can use it to control the manual speed?

jbrazio, 2022-01-20:
@Antiath thank you for the comment. Indeed the documentation is lacking.. the key feature was a bit slapped into the source code.

@dwilbourn618 you need to connect a potentiometer to and ADC channel and define that channel on the config using `define UI_KAP_ADC_CHANNEL`, then the position where the pot is at will set the speed that focuser will move when a key is pressed.

dwilbourn618, 2022-01-20:
Thank you!

max2206, 2022-02-25:
> @Antiath thank you for the comment. Indeed the documentation is lacking.. the key feature was a bit slapped into the source code.
>
> @dwilbourn618 you need to connect a potentiometer to and ADC channel and define that channel on the config using `define UI_KAP_ADC_CHANNEL`, then the position where the pot is at will set the speed that focuser will move when a key is pressed.

OK to which pins need one to connect a pot

Closed 2020-10-24.

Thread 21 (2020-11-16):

Ardufocus components

ApoEvans, 2020-11-16:
Hello João,

I want to build the arduino focuser using your code and schematics as a reference.
Can I succeed without using the resistance and thermistor and if not could you please elaborate on their function on the project ?
I do not have a thermistor at hand so, can I substitute thermistor with a resistance ?

Best Regards

Apo

jbrazio, 2020-11-19:
Hi Apo,

Their purpose is to report back temperature to the ASCOM driver which in turn is used by the imaging program to (re)focus your imaging train every X degrees delta in temperature.

The original Moonlite has builtin on the focuser firmware an automatic temperature compensation algorithm which does not rely on the imaging software that will automatic move a x amount of steps based on temperature delta.. but this doesn't work that good and I decided not to implement it.

I would say that the system will even work without the components but the best would be to populate the thermistor location with a 10K resistor, it should always report back 25C.

ApoEvans, 2020-11-19:
<!--
/* Font Definitions */
@font-face
	{font-family:"Cambria Math";
	panose-1:2 4 5 3 5 4 6 3 2 4;}
@font-face
	{font-family:Calibri;
	panose-1:2 15 5 2 2 2 4 3 2 4;}
/* Style Definitions */
p.MsoNormal, li.MsoNormal, div.MsoNormal
	{margin:0in;
	font-size:11.0pt;
	font-family:"Calibri",sans-serif;}
a:link, span.MsoHyperlink
	{mso-style-priority:99;
	color:blue;
	text-decoration:underline;}
.MsoChpDefault
	{mso-style-type:export-only;}
@page WordSection1
	{size:8.5in 11.0in;
	margin:1.0in 1.0in 1.0in 1.0in;}
div.WordSection1
	{page:WordSection1;}
-->Hi João, I will try it with resistor you suggested. Thank you, Apo Sent from Mail for Windows 10 From: João BrázioSent: Thursday, November 19, 2020 1:40 PMTo: jbrazio/ardufocusCc: ApoEvans; AuthorSubject: Re: [jbrazio/ardufocus] Ardufocus components (#21) Hi Apo,Their purpose is to report back temperature to the ASCOM driver which in turn is used by the imaging program to (re)focus your imaging train every X degrees delta in temperature.The original Moonlite has builtin on the focuser firmware an automatic temperature compensation algorithm which does not rely on the imaging software that will automatic move a x amount of steps based on temperature delta.. but this doesn't work that good and I decided not to implement it.I would say that the system will even work without the components but the best would be to populate the thermistor location with a 10K resistor, it should always report back 25C.—You are receiving this because you authored the thread.Reply to this email directly, view it on GitHub, or unsubscribe.

Closed 2020-12-12.

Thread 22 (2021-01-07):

Will not compile when DRV8825 selected.

zytryx, 2021-01-07:
I can not compile the ino file if I select DRV8825 as the driver.  Get an error about motor 1 not having a driver selected.

Also wiring image does not seem to match pin assignments

Closed 2021-02-02.

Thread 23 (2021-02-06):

Compatibility Arduino Nano Every

piropiro24, 2021-02-06:
Hi! any compatibility with arduino nano every? It got me "No supported platform found" error

jbrazio, 2021-02-21:
Hi ! It is not supported and I don't have any around so I could test/implement the support for it.

Closed 2021-06-11.

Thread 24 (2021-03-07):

Ardufocus is not recognized by the Moolite ASCOM driver

nikivan1, 2021-03-07:
Compiled and uploaded the firmware to Arduino Mini. I am able to communicate with it from the Moonlite Single Focuser
 v1.4 app, but the Moonlite DRO Focuser Driver (downloaded from focuser.com) does not show any devices in the Moonlite Focus Setup menu. I am running the latest version 6.5 of the ASCOM Platform.

nikivan1, 2021-03-07:
Found about the reset capacitor. With 100nF between Reset and D3 and the appropriate config settings it works.

bakosmi, 2022-07-12:
please what config settings? i have the same issue and struggle to resolve it. many thanks!

jbrazio, 2022-07-15:
You need to add a capacitor, otherwise the arduino will reset at every serial connection and the moonlite driver will not recognize the focuser as connected.

bakosmi, 2022-07-15:
i have added salvaged led diode between reset and 5v and it works fine - many thanks! :-)

Closed 2021-03-07.

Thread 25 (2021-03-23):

Configuring motor 2 using the printed board

FearL0rd, 2021-03-23:
Im trying to use the second motor using printed board and Im getting this error when I try to compile

The build instructions says to use this pinout https://ardufocus.com/manual/build-instructions/

  #define MOTOR2_PINOUT  A2,   6,   5,     4,     3,   2

Error:
sketch\a4988.h:70:12: note:   no known conversion for argument 1 from '<brace-enclosed initializer list>' to 'const a4988::pinout_t&'
exit status 1
'A2' was not declared in this scope

this is the PCB Im using https://github.com/jbrazio/ardufocus-schematics/raw/master/ardufocus/ardufocus-top.png

FearL0rd, 2021-03-23:
I was able to use 20 to call A2

#define MOTOR2_PINOUT 20, 6, 5, 4, 3, 2

Closed 2021-06-11.

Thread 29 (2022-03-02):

#define MOTOR1_USE_DRV8825_DRIVER ( DRV8825) not working

luizrsilveira1, 2022-03-02:
First of all, thank you for this amazing project. Is the only DIY focuser I can use on NINA without any issues.

However, I can't figure out how to make it work with the DRV8825.

On the [config.h](https://github.com/jbrazio/ardufocus/blob/master/ardufocus/config.h) file, there are 3 options, which the user must select only one. This is the default:

```
#define MOTOR1_USE_A4988_DRIVER
//#define MOTOR1_USE_DRV8825_DRIVER
//#define MOTOR1_USE_ULN2003_DRIVER
```

That is, the user can choose between the A4988, the ULN2003, and the DRV8825. This is also mentioned on the "Firmware" page with instructions here: https://ardufocus.com/manual/firmware/

Unfortunately, the DRV8825 doesn't seem to have been implemented yet. Forgive me if I'm wrong. :P

Right below these options, in the config.h file, I found two "IF"s. One for the A4988, and another for the ULN2003. But none for the DRV8825:

```
// Driver pin-out definition
// Define bellow the pin-out for your specific driver.
#ifdef MOTOR1_USE_ULN2003_DRIVER
  //                    IN1, IN2, IN3, IN4
  #define MOTOR1_PINOUT   2,   3,   4,   5
#endif

#ifdef MOTOR1_USE_A4988_DRIVER
  //                    MS1, MS2, MS3, SLEEP,  STEP, DIR
  #define MOTOR1_PINOUT  12,  11,  10,     8,     7,   6
#endif
```

After that, the next lines refer to other settings, such as sleep when idle, etc.

That said, as expected, we can't compile or upload the code to the Arduino when the option "MOTOR1_USE_DRV8825_DRIVER" is defined.

As I'm learning how to code yet, I'm not sure if this is in fact something that needs to be implemented, or if I'm missing something.

Thank you!

-----
EDIT: Looking on other files, I found this on the [assert.h](https://github.com/jbrazio/ardufocus/blob/master/ardufocus/assert.h):

```
// DRV8825 driver hack --------------------------------------------------------
#if defined(MOTOR2_USE_DRV8825_DRIVER)
  #define MOTOR2_USE_A4988_DRIVER
#endif
```

Even so, the code won't compile.

Can I interpret that defining "MOTOR1_USE_A4988_DRIVER" on config.h would work just fine with the DRV8825? Of course, correcting the connections for the variations of the DRV8825.

Closed 2022-04-27.

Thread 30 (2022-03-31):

Use of Ardufocus with __AVR_ATmega2560__ possible?

MariaJesusSogorbAmoros, 2022-03-31:
I am trying to build my Ardufocus and found out, this platform is not configured.
is it not possible the use of this with MEGA2560, to avoid supplying the motor with external VCC?

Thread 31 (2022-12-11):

Firmware Issue

RhoLuke, 2022-12-11:
I've made some ardufocus in the past (like one year ago), and they all work fine. In the last month I tried to make another one, but this time I have a problem. I can't connect properly the arduino, both the moonlight driver and the Ardufocus driver show a connection problem. The wired thing is that I've upload the same skecth of the ardufocus that I've made in the past and they work fine!
It is pheraps an Arduino IDE problem, maybe due to the libraries update?

jbrazio, 2022-12-20:
Hi ! Did you put the pull up cap to avoid the reset when the serial connects ? Check #24

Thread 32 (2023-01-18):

focuser jumps to zero position quite randomly while searching for focus INDI, EKOS

astroberlin, 2023-01-18:
Hi João, thank you for the great project.

I have two focusers running 2a on an UNO and controlled by INDI Moonlite DRO driver in EKOS, Kstars.

During focusing, the focuser will randomly jump back to the zero position, as if it is misreading a command.  Any settings/timings I can optimize to prevent this?

Thank you.

Mr-Groch, 2023-07-23:
I'm experiencing the same issue also on ASCOM driver (moonlite and native)

ChrisN4gel, 2024-06-23:
Hi João, thanks for Ardufocus from me as well... I love it.
I also have the issue with the position being 0 sporadically. I am using it on two rigs with China-Unos (CH340 Driver from NanjingQinhengMicroelectronics) and the stepper motors are both 28BYJ-48 / ULN2003

But anyway, great project which brought motorized focussing to my telescopes.  :-)
Thanks, Christian

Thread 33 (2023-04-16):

Arduino firmware location

RobertoVolpini, 2023-04-16:
Hello, I would like to use this Ardufocus but I found only .cpp files that are not compatiple with Arduino IDLE, how and where I can download the Arduino firmware?
Thanks in advance for your feedback
Roberto

radon199, 2024-06-10:
@RobertoVolpini

There is a .ino extension file in the repo which you can load into the Arduino IDE.

This will load this ino stub file into the IDE along with all the cpp files and uploading from here will build and upload the whole of the firmware.

The documentation is lacking in this area so I can understand the confusion, I had the same issue myself.

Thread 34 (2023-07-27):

Motore freezer when stopped

B3rto83, 2023-07-27:
Hi, i built the project and everything works fine, except for One issue.
In N.i.n.a. when the motor Is moving (and only in this case) of i clic the X for stop It the motor stops but It remains flagged "Is moving" and all that i have tò do Is disconnect and reset the borad. All control buttons became disabled.

But if i leave motor to complete its command and It stops itself, everything goes well.

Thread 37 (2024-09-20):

Doesn't work with archlinux kstar 3.7.2 ?

wadouk, 2024-09-20:
I switch from astroberry (kstars 3.6) to archastro (kstars 3.7.2, libindi 2.0.9) because of an other problem and there is no reaction from ardufocus. Does anyone use a recent version of kstars/indi ?

wadouk, 2024-09-20:
Nevermind, the problem should be elsewhere. Just reflash the system, take care of the selection of the port and it's OK.

Closed 2024-09-20.

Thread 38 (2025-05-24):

Is it possible to use A6 for temperature reading?

pulsar123, 2025-05-24:
I already have a PCB with the thermistor soldered to A6 of Arduino Nano. Would it be possible to use A6 instead of A0 for temperature reading?

pulsar123, 2025-05-24:
Never mind, I cut the PCB track, and resoldered the thermistor. It works now.

Closed 2025-05-24.

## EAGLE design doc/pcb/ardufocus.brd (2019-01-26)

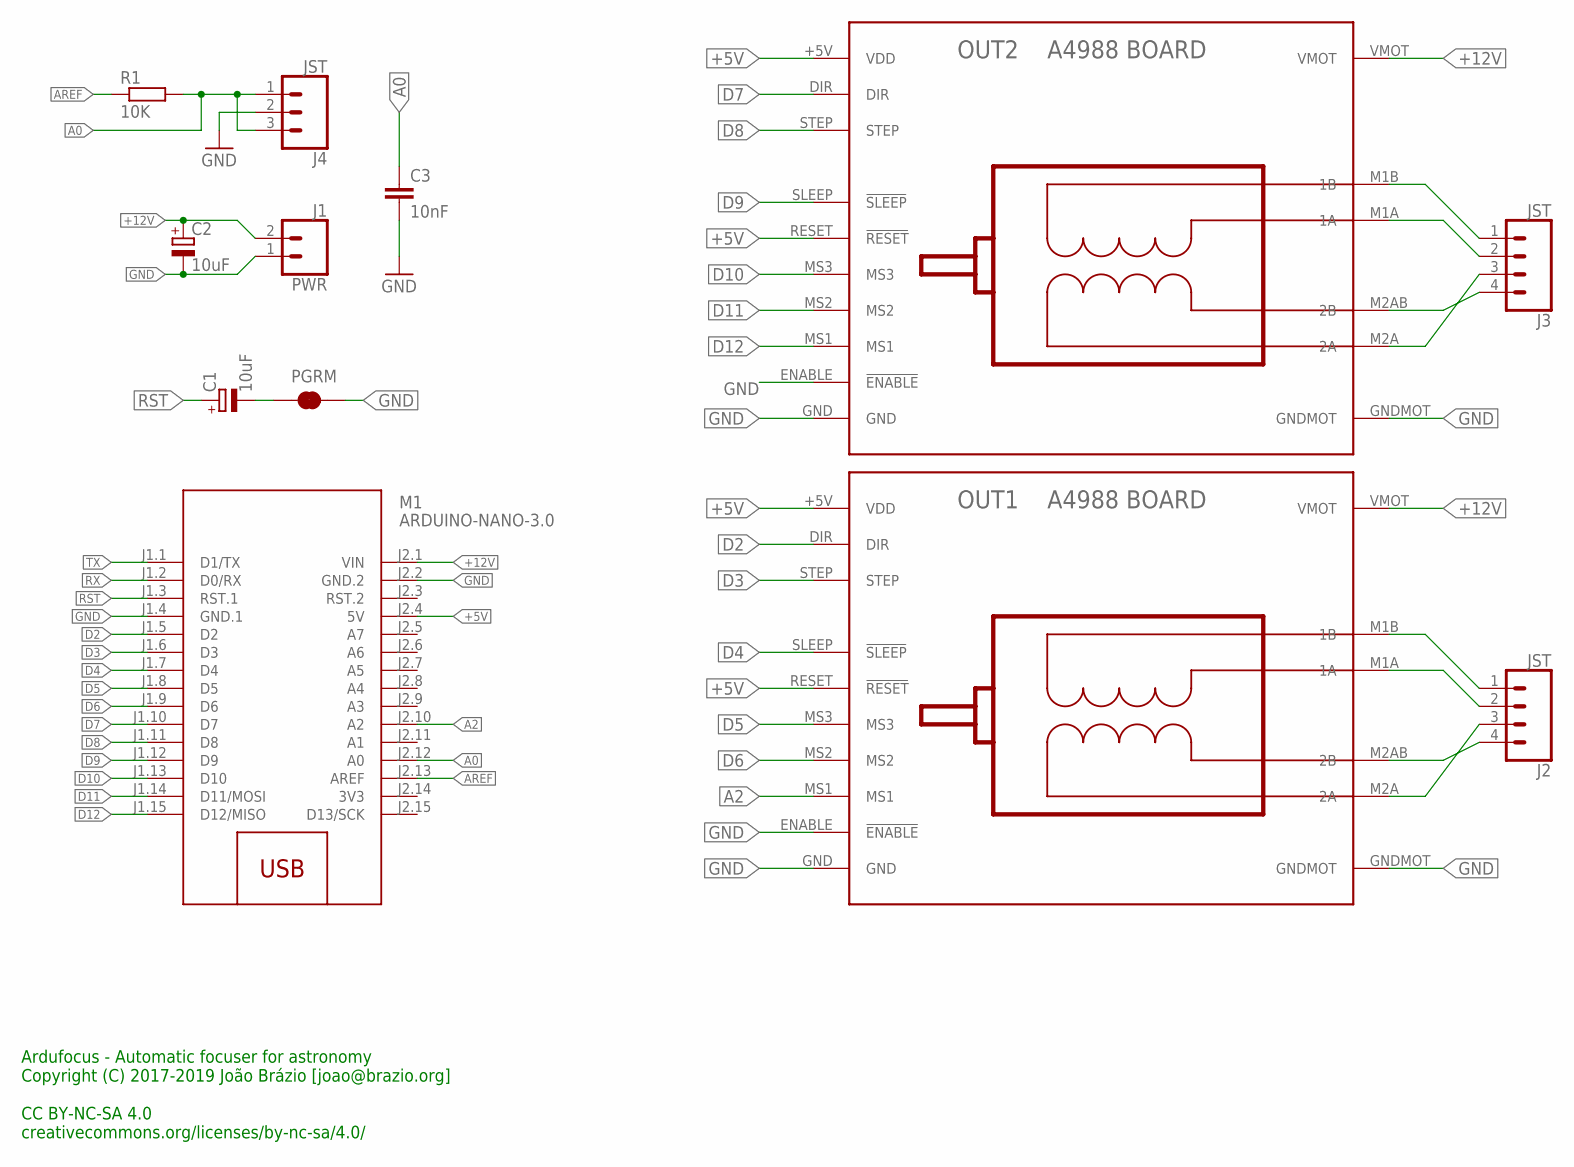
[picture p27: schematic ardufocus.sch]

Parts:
C1: 10uF; E1,8-4
C2: 10uF; E2,5-6E
C3: 10nF; C3216
J1: PWR; SCREWTERMINAL-5MM-2
J2, J3: JST; JST-4-PTH-VERT
J4: JST; JST-3-PTH-VERT
M1: ARDUINO-NANO-3.0
OUT1, OUT2: BOARD_A4988
PGRM: JUMPER-SMT_2_NC_TRACE_SILK; SMT-JUMPER_2_NC_TRACE_SILK
R1: 10K; M1206

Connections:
3V3: M1.J2.14 (3V3)
+5V: M1.J2.4 (5V), OUT1.+5V (VDD), OUT1.RESET (!RESET), OUT2.+5V (VDD), OUT2.RESET (!RESET)
+12V: C2.+, J1.2, M1.J2.1 (VIN), OUT1.VMOT, OUT2.VMOT
A0: C3.1, J4.1, J4.3, M1.J2.12 (A0), R1.2
A2: M1.J2.10 (A2), OUT1.MS1
AREF: M1.J2.13 (AREF), R1.1
D2: M1.J1.5 (D2), OUT1.DIR
D3: M1.J1.6 (D3), OUT1.STEP
D4: M1.J1.7 (D4), OUT1.SLEEP (!SLEEP)
D5: M1.J1.8 (D5), OUT1.MS3
D6: M1.J1.9 (D6), OUT1.MS2
D7: M1.J1.10 (D7), OUT2.DIR
D8: M1.J1.11 (D8), OUT2.STEP
D9: M1.J1.12 (D9), OUT2.SLEEP (!SLEEP)
D10: M1.J1.13 (D10), OUT2.MS3
D11: M1.J1.14 (D11/MOSI), OUT2.MS2
D12: M1.J1.15 (D12/MISO), OUT2.MS1
GND: C2.-, C3.2, J1.1, J4.2, M1.J1.4 (GND.1), M1.J2.2 (GND.2), OUT1.ENABLE (!ENABLE), OUT1.GND, OUT1.GNDMOT, OUT2.ENABLE (!ENABLE), OUT2.GND, OUT2.GNDMOT, PGRM.2
unnamed: J3.1, OUT2.M1B (1B)
unnamed: C1.-, PGRM.1
unnamed: J2.3, OUT1.M2A (2A)
unnamed: J3.2, OUT2.M1A (1A)
unnamed: J3.4, OUT2.M2AB (2B)
unnamed: J2.1, OUT1.M1B (1B)
unnamed: J2.2, OUT1.M1A (1A)
unnamed: J2.4, OUT1.M2AB (2B)
unnamed: J3.3, OUT2.M2A (2A)
RST: C1.+, M1.J1.3 (RST.1)
RX: M1.J1.2 (D0/RX)
TX: M1.J1.1 (D1/TX)

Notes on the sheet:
Ardufocus - Automatic focuser for astronomy Copyright (C) 2017-2019 João Brázio [joao@brazio.org] CC BY-NC-SA 4.0 creativecommons.org/licenses/by-nc-sa/4.0/

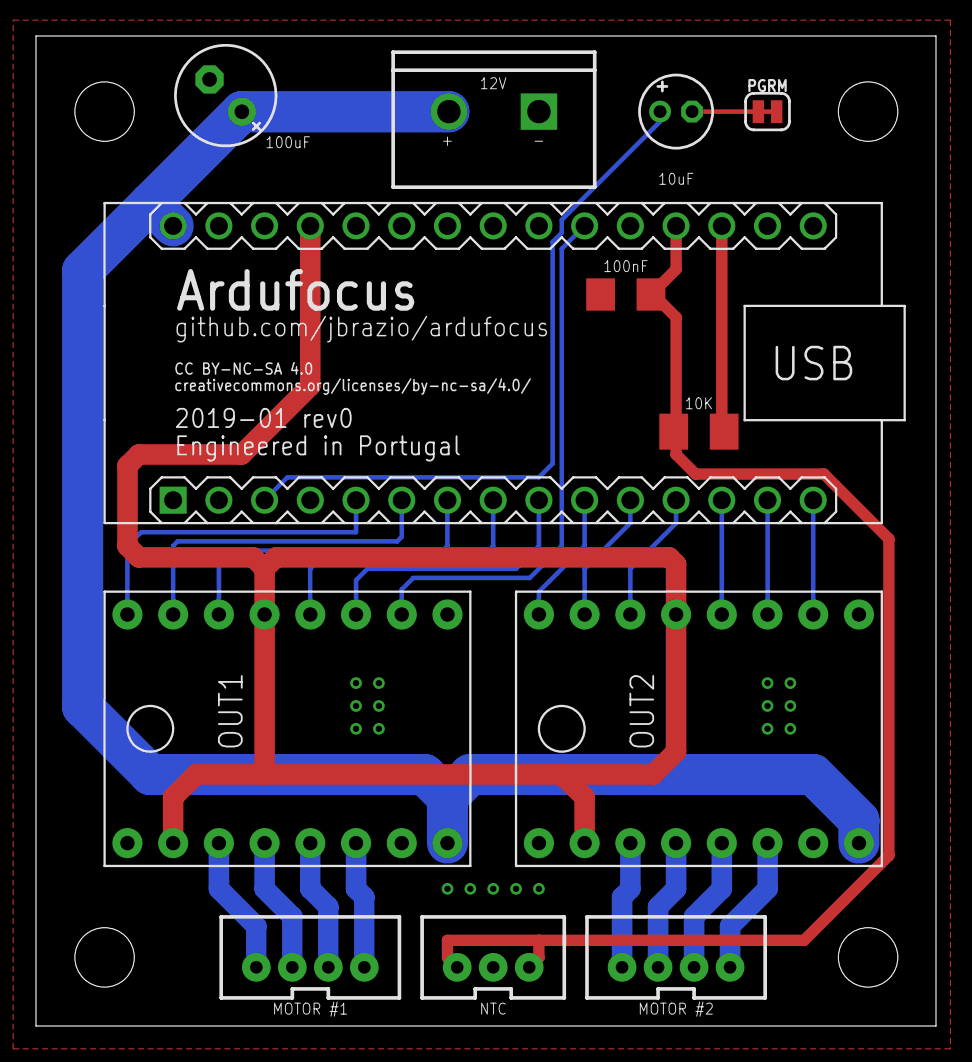
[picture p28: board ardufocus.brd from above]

Board: 2 copper layers, 50.0 x 55.0 mm, 16 parts (0 on the bottom side), 27 nets.

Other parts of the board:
U$1, U$2, U$3, U$4: STAND-OFF

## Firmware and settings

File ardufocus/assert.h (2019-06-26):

/**
 * Ardufocus - Moonlite compatible focuser
 * Copyright (C) 2017-2019 João Brázio [joao@brazio.org]
 *
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
 */

#ifndef __ASSERT_H__
#define __ASSERT_H__

// Defaults -------------------------------------------------------------------
#define TIMER0_PSCL 64
#define TIMER0_FREQ 5000L // Hz
#define TIMER0_OCRA (((F_CPU/TIMER0_PSCL) / TIMER0_FREQ)  -1)
#define TIMER0_TICK (1000000L  / TIMER0_FREQ) // uS

#define TIMER2_PSCL 1024
#define TIMER2_FREQ 160L // Hz
#define TIMER2_OCRA (((F_CPU/TIMER0_PSCL) / TIMER0_FREQ)  -1)
#define TIMER2_TICK (1000000L  / TIMER0_FREQ) // uS

#define DEFAULT_MAX_SPEED    250
#define DEFAULT_MIN_SPEED     25
#define DEFAULT_SLEEP_TIMEOUT 15

// User warnings --------------------------------------------------------------
#if defined(ENABLE_REMOTE_RESET)
  //#warning Remote reset is enabled, make sure your bootloader is updated !
#endif

// Invalid configurations -----------------------------------------------------
#if defined(ENABLE_DTR_RESET)
  #if !defined(DTR_RESET_PINOUT)
    #error DTR_RESET_PINOUT is active but DTR_RESET_PINOUT is missing.
    #error Please review the config.h file.
  #endif

  #if !defined(USE_EEPROM)
    #error ENABLE_DTR_RESET requiures USE_EEPROM to be active aswell.
    #error Please review the config.h file.
  #endif
#endif

// DRV8825 driver hack --------------------------------------------------------
#if defined(MOTOR1_USE_DRV8825_DRIVER)
  #define MOTOR1_USE_A4988_DRIVER
#endif

// Duplicate driver check -----------------------------------------------------
#if defined(MOTOR1_USE_A4988_DRIVER) && defined(MOTOR1_USE_ULN2003_DRIVER)
  #error More than one stepper driver selected for motor #1
  #error Please review the config.h file.
#elif defined(MOTOR1_USE_A4988_DRIVER) || defined(MOTOR1_USE_ULN2003_DRIVER)
  #define MOTOR1_HAS_DRIVER
#else
  // Motor 1 is optional
#endif

#if defined(MOTOR2_USE_A4988_DRIVER) && defined(MOTOR2_USE_ULN2003_DRIVER)
  #error More than one stepper driver selected for motor #2
  #error Please review the config.h file.
#elif defined(MOTOR2_USE_A4988_DRIVER) || defined(MOTOR2_USE_ULN2003_DRIVER)
  #define MOTOR2_HAS_DRIVER
#else
  // Motor 2 is optional
#endif

// DRV8825 driver hack --------------------------------------------------------
#if defined(MOTOR2_USE_DRV8825_DRIVER)
  #define MOTOR2_USE_A4988_DRIVER
#endif

// Optional motor 2 -----------------------------------------------------------
#if !defined(MOTOR1_HAS_DRIVER) && defined(MOTOR1_PINOUT)
  #error No motor pinout defined for motor #1.
  #error Please review the config.h file.
#elif defined(MOTOR1_HAS_DRIVER) && !defined(MOTOR1_PINOUT)
  #error No stepper driver selected for motor #1.
  #error Please review the config.h file.
#endif

#if !defined(MOTOR2_HAS_DRIVER) && defined(MOTOR2_PINOUT)
  #error No motor pinout defined for motor #2.
  #error Please review the config.h file.
#elif defined(MOTOR2_HAS_DRIVER) && !defined(MOTOR2_PINOUT)
  #error No stepper driver selected for motor #2.
  #error Please review the config.h file.
#endif

#if !defined(MOTOR1_HAS_DRIVER) && !defined(MOTOR2_HAS_DRIVER)
  #error At least ONE motor must be defined.
  #error Please review the config.h file.
#endif

// High resolution mode -------------------------------------------------------
#if defined(MOTOR1_HIGH_RESOLUTION) || defined(MOTOR2_HIGH_RESOLUTION)
  #define HIGH_RESOLUTION_MODE
#endif

// Sanity check for motor one -------------------------------------------------
#ifdef MOTOR1_HAS_DRIVER
  // Speed control ------------------------------------------------------------
  #ifndef MOTOR1_MAX_SPEED
    #define MOTOR1_MAX_SPEED DEFAULT_MAX_SPEED
  #endif

  #ifndef MOTOR1_MIN_SPEED
    #define MOTOR1_MIN_SPEED DEFAULT_MIN_SPEED
  #endif

  // Miscellaneous ------------------------------------------------------------
  #ifndef MOTOR1_INVERT_DIRECTION
    #define MOTOR1_INVERT_DIRECTION false
  #else
    #undef MOTOR1_INVERT_DIRECTION
    #define MOTOR1_INVERT_DIRECTION true
  #endif

  #ifndef MOTOR1_SLEEP_WHEN_IDLE
    #define MOTOR1_SLEEP_WHEN_IDLE false
  #else
    #undef MOTOR1_SLEEP_WHEN_IDLE
    #define MOTOR1_SLEEP_WHEN_IDLE true
  #endif

  #ifndef MOTOR1_SLEEP_TIMEOUT
    #define MOTOR1_SLEEP_TIMEOUT DEFAULT_SLEEP_TIMEOUT
  #endif
#endif

// Sanity check for motor two -------------------------------------------------
#ifdef MOTOR2_HAS_DRIVER
  // Speed control ------------------------------------------------------------
  #ifndef MOTOR2_MAX_SPEED
    #define MOTOR2_MAX_SPEED DEFAULT_MAX_SPEED
  #endif

  #ifndef MOTOR2_MIN_SPEED
    #define MOTOR2_MIN_SPEED DEFAULT_MIN_SPEED
  #endif

  // Miscellaneous ------------------------------------------------------------
  #ifndef MOTOR2_INVERT_DIRECTION
    #define MOTOR2_INVERT_DIRECTION false
  #else
    #undef MOTOR2_INVERT_DIRECTION
    #define MOTOR2_INVERT_DIRECTION true
  #endif

  #ifndef MOTOR2_SLEEP_WHEN_IDLE
    #define MOTOR2_SLEEP_WHEN_IDLE false
  #else
    #undef MOTOR2_SLEEP_WHEN_IDLE
    #define MOTOR2_SLEEP_WHEN_IDLE true
  #endif

  #ifndef MOTOR2_SLEEP_TIMEOUT
    #define MOTOR2_SLEEP_TIMEOUT DEFAULT_SLEEP_TIMEOUT
  #endif
#endif

// Acceleration sanity checks -------------------------------------------------
#if defined(USE_LINEAR_ACCEL) || defined(USE_TRAPEZOID_ACCEL) || defined(USE_SMOOTHSTEP_ACCEL)
  #define HAS_ACCELERATION

  #ifndef ACCEL_DURATION
    #define ACCEL_DURATION 250
  #elif (ACCEL_DURATION < 100)
    #warning The acceleration duration is less than 100 steps.
    #warning Maybe you should consider disabling acceleration at al ?
  #endif

  #ifndef ACCEL_MIN_STEPS
    #define ACCEL_MIN_STEPS 10
  #elif (ACCEL_MIN_STEPS < 1)
    #error ACCEL_MIN_STEPS cannot be lower than 1 step.
    #error Please review the config.h file.
  #endif

  #if (ACCEL_MIN_STEPS >= ACCEL_DURATION)
    #error ACCEL_MIN_STEPS must be lower than ACCEL_DURATION.
    #error Please review the config.h file.
  #endif
#endif

#ifndef NTC_ADC_CHANNEL
  #error You must assign a analog channel to the thermistor.
  #error Please review the config.h file.
#else
    #if !defined(NTC_NOMINAL_TEMP) || !defined(NTC_BCOEFFICIENT) || !defined(NTC_NOMINAL_VAL) || !defined(NTC_RESISTOR_VAL)
      #error Thermistor configuration is not valid.
      #error Please review the config.h file.
    #endif

    #ifndef NTC_MIN_RAW_VALUE
      #define NTC_MIN_RAW_VALUE 50
    #endif

    #ifndef NTC_MAX_RAW_VALUE
      #define NTC_MAX_RAW_VALUE 950
    #endif
#endif

// USER INTERFACE: Keyboard ---------------------------------------------------
#if defined(USE_UI_KAP)
  #if defined(UI_KAP_BUTTON_DEBOUNCE) && (UI_KAP_BUTTON_DEBOUNCE < 1 || UI_KAP_BUTTON_DEBOUNCE > 255)
    #undef UI_KAP_BUTTON_DEBOUNCE
  #endif

  #if !defined(UI_KAP_BUTTON_DEBOUNCE)
    #define UI_KAP_BUTTON_DEBOUNCE 15
  #endif

  #if !defined(UI_KAP_FWD_BUTTON_PIN) || !defined(UI_KAP_BWD_BUTTON_PIN)
    #error KAP configuration is not valid.
    #error Please define UI_KAP_FWD_BUTTON_PIN and UI_KAP_BWD_BUTTON_PIN
  #endif
#endif

#endif

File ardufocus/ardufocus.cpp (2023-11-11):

/**
 * Ardufocus - Moonlite compatible focuser
 * Copyright (C) 2017-2019 João Brázio [joao@brazio.org]
 *
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
 */

#include "ardufocus.h"

// --------------------------------------------------------------------------
// Globals ------------------------------------------------------------------
// --------------------------------------------------------------------------
eeprom_map_t  g_config;

#ifdef MOTOR1_HAS_DRIVER
  stepper* g_motor1 = &motor1drv;
#endif

#ifdef MOTOR2_HAS_DRIVER
  stepper* g_motor2 = &motor2drv;
#endif


int main(void)
{
  // --------------------------------------------------------------------------
  // DEBUG --------------------------------------------------------------------
  // --------------------------------------------------------------------------
  #ifdef DEBUG_ISR
  DDRB = bit(PB5);
  DDRC = bit(PC3) | bit(PC2);
  #endif

  // --------------------------------------------------------------------------
  // EEPROM -------------------------------------------------------------------
  // --------------------------------------------------------------------------
  eeprom_init(&g_config);


  // --------------------------------------------------------------------------
  // DTR Serial Reset ---------------------------------------------------------
  // --------------------------------------------------------------------------
  dtr_disable();


  // --------------------------------------------------------------------------
  // Disable Watchdog ---------------------------------------------------------
  // --------------------------------------------------------------------------
  wdt_disable();


  // --------------------------------------------------------------------------
  // Disable global interrupts ------------------------------------------------
  // --------------------------------------------------------------------------
  cli();


  // --------------------------------------------------------------------------
  // Load settings ------------------------------------------------------------
  // --------------------------------------------------------------------------
  #ifdef MOTOR1_HAS_DRIVER
    g_motor1->set_current_position(g_config.position_m1);
  #endif

  #ifdef MOTOR2_HAS_DRIVER
    g_motor2->set_current_position(g_config.position_m2);
  #endif


  // --------------------------------------------------------------------------
  // Timer0 ISR init routine --------------------------------------------------
  // --------------------------------------------------------------------------
  // Cleanup all the relevant registers
  TCCR0A = 0; TCCR0B = 0; TIMSK0 = 0;
  TIFR0  = 0; TCNT0  = 0; OCR0A  = 0; OCR0B = 0;

  // set waveform generation mode to CTC, top OCR0A
  TCCR0A |= bit(WGM01);

  // set clock select to clk/64
  TCCR0B |= bit(CS01) | bit(CS00);

  // output Compare A Match Interrupt Enable
  TIMSK0 |= bit(OCIE0A);

  // sets the Output Compare Register values
  OCR0A = TIMER0_OCRA;


  // --------------------------------------------------------------------------
  // Timer2 ISR init routine --------------------------------------------------
  // --------------------------------------------------------------------------
  // Cleanup all the relevant registers
  TCCR2A = 0; TCCR2B = 0; TIMSK2 = 0;
  TIFR2  = 0; TCNT2  = 0; OCR2A  = 0; OCR2B = 0;

  // set waveform generation mode to CTC, top OCR0A
  TCCR2A |= bit(WGM21);

  // set clock select to clk/64
  TCCR2B |= bit(CS22) | bit(CS21) | bit(CS20);

  // output Compare A Match Interrupt Enable
  TIMSK2 |= bit(OCIE2A);

  // sets the Output Compare Register values
  OCR2A = TIMER2_OCRA;


  // --------------------------------------------------------------------------
  // ADC init routine ---------------------------------------------------------
  // --------------------------------------------------------------------------
  Analog::setup();


  // --------------------------------------------------------------------------
  // User interface -----------------------------------------------------------
  // --------------------------------------------------------------------------
  UI::setup();


  // --------------------------------------------------------------------------
  // Motor #1 init routine ----------------------------------------------------
  // --------------------------------------------------------------------------
  #ifdef MOTOR1_HAS_DRIVER
    g_motor1->set_invert_direction(MOTOR1_INVERT_DIRECTION);
    g_motor1->set_sleep_when_idle(MOTOR1_SLEEP_WHEN_IDLE);
    g_motor1->set_sleep_timeout(MOTOR1_SLEEP_TIMEOUT);
    g_motor1->set_max_speed(MOTOR1_MAX_SPEED);
    g_motor1->set_min_speed(MOTOR1_MIN_SPEED);
    g_motor1->init();
    if (g_config.speed_m1 != 0) { g_motor1->set_speed(g_config.speed_m1); }
    if (g_config.half_step_m1) { g_motor1->set_half_step(); }
  #endif

  #ifdef MOTOR2_HAS_DRIVER
    g_motor2->set_invert_direction(MOTOR2_INVERT_DIRECTION);
    g_motor2->set_sleep_when_idle(MOTOR2_SLEEP_WHEN_IDLE);
    g_motor2->set_sleep_timeout(MOTOR2_SLEEP_TIMEOUT);
    g_motor2->set_max_speed(MOTOR2_MAX_SPEED);
    g_motor2->set_min_speed(MOTOR2_MIN_SPEED);
    g_motor2->init();
    if (g_config.speed_m2 != 0) { g_motor2->set_speed(g_config.speed_m2); }
    if (g_config.half_step_m2) { g_motor2->set_half_step(); }
  #endif


  // --------------------------------------------------------------------------
  // Enable global interrupts -------------------------------------------------
  // --------------------------------------------------------------------------
  sei();


  // --------------------------------------------------------------------------
  // Loop routine -------------------------------------------------------------
  // --------------------------------------------------------------------------
  for(;;)
  {
    comms.receive();

    UI::update_display();
    UI::fetch_key_state();
  }

  // Someone made an Opsie !
  // Code should not reach this
  return 0;
}

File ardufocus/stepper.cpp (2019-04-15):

/**
 * Ardufocus - Moonlite compatible focuser
 * Copyright (C) 2017-2019 João Brázio [joao@brazio.org]
 *
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
 */

#include "stepper.h"

/**
 * @brief [brief description]
 * @details [long description]
 *
 */
void stepper::init()
{
  ATOMIC_BLOCK(ATOMIC_RESTORESTATE) {
    m_speed = 2;
    m_ovf_counter = 0;
  }
}


/**
 * @brief [brief description]
 * @details [long description]
 *
 */
void stepper::move()
{
  m_ovf_counter = 0;
  m_position.moving = true;
}


/**
 * @brief [brief description]
 * @details [long description]
 *
 */
bool stepper::is_moving()
{
  const bool b = (m_position.moving);
  return b;
}


/**
 * @brief [brief description]
 * @details [long description]
 *
 */
void stepper::halt()
{
  ATOMIC_BLOCK(ATOMIC_RESTORESTATE) {
    m_position.target = m_position.current;
    m_position.moving = false;
  }
}


/**
 * @brief [brief description]
 * @details [long description]
 *
 */
uint32_t stepper::get_current_position()
{
  const uint32_t c = m_position.current;
  return c;
}



/**
 * @brief [brief description]
 * @details [long description]
 *
 */
void stepper::set_current_position(const uint32_t& target) {
  ATOMIC_BLOCK(ATOMIC_RESTORESTATE) {
    m_position.current = target;
    m_position.target  = target;
  }
}


/**
 * @brief [brief description]
 * @details [long description]
 *
 */
uint16_t stepper::get_speed()
{
  const uint16_t s = m_speed;
  return s;
}


/**
 * @brief [brief description]
 * @details [long description]
 *
 */
void stepper::set_speed(const uint16_t& target)
{
  ATOMIC_BLOCK(ATOMIC_RESTORESTATE) {
    m_speed = target;
  }
}


/**
 * @brief [brief description]
 * @details [long description]
 *
 */
uint32_t stepper::get_target_position()
{
  const uint32_t t = m_position.target;
  return t;
}



/**
 * @brief [brief description]
 * @details [long description]
 *
 */
void stepper::set_target_position(const uint32_t& target) {
  ATOMIC_BLOCK(ATOMIC_RESTORESTATE) {
    m_position.target = target;

    #ifdef HAS_ACCELERATION
      m_position.relative = 0;

      m_position.distance = (m_position.current > target)
        ? m_position.current - target
        : target - m_position.current;

      if (m_position.distance >= ACCEL_MIN_STEPS)
      {
        #if defined(USE_LINEAR_ACCEL)
          m_position.easein  = m_position.distance >> 1;
          m_position.easeout = m_position.easein;

        #elif defined(USE_TRAPEZOID_ACCEL) || defined(USE_SMOOTHSTEP_ACCEL)
          if (m_position.distance < (ACCEL_DURATION << 1))
          {
            m_position.easein  = m_position.distance >> 1;
            m_position.easeout = m_position.easein;
          }
          else
          {
            m_position.easein  = ACCEL_DURATION;
            m_position.easeout = m_position.distance - ACCEL_DURATION;
          }
        #endif
      }
    #endif
  }
}


/**
 * @brief [brief description]
 * @details [long description]
 *
 */
void stepper::tick()
{
  // Movement guard
  if (! m_position.moving) { sleep(); return; }

  // Step frequency generator
  if((m_ovf_counter++) < (TIMER0_FREQ / (m_set_speed<<1)) -1) { return; }
  m_ovf_counter = 0;

  // Speed control
  // We're not 100% moonlite compatible here: the PPS speed value you select
  // on the driver acts as a divider of *_MAX_SPEED set on the config file.
  static uint8_t counter = 0;
  if((counter++) % (m_speed>>1) != 0) { return; }

  // Move outwards
  if (m_position.target > m_position.current) {
    if ((m_invert_direction) ? step_cw() : step_ccw()) { update_position(1); }
  }

  // Move inwards
  else if (m_position.target < m_position.current) {
    if ((m_invert_direction) ? step_ccw() : step_cw()) { update_position(-1); }
  }

  // Stop movement
  else { halt(); }
}


#ifdef HAS_ACCELERATION
  /**
   * @brief [brief description]
   * @details [long description]
   *
   */
  void stepper::update_freq()
  {
    if (m_position.distance >= ACCEL_MIN_STEPS)
    {
      #if defined(USE_LINEAR_ACCEL)
        const float s = (m_position.relative <= m_position.easein)
          ? m_position.relative : m_position.distance - m_position.relative;
        const float f = map(s, 0, m_position.easein, 0.0, 1.0);

      #elif defined(USE_TRAPEZOID_ACCEL)
        const float s = (m_position.relative <= m_position.easein)
          ? m_position.relative : (m_position.relative >= m_position.easeout)
          ? m_position.distance - m_position.relative : ACCEL_DURATION;
        const float f = map(s, 0, ACCEL_DURATION, 0.0, 1.0);

      #elif defined(USE_SMOOTHSTEP_ACCEL)
        const float f = util::smootheststep(0, m_position.easein, m_position.relative) *
          (1.0 - util::smootheststep(m_position.easeout, m_position.distance, m_position.relative));
      #endif

      m_set_speed = util::lerp(m_min_speed, m_max_speed, f);

    } else { m_set_speed = m_min_speed; }
  }
#endif

/**
 * @brief [brief description]
 * @details [long description]
 *
 */
void stepper::update_position(const int8_t &direction)
{
  ATOMIC_BLOCK(ATOMIC_RESTORESTATE) {
    m_position.current += direction;          // Update the global position

    #ifdef HAS_ACCELERATION
      ++m_position.relative;  // Update the relative position
      update_freq();          // Update the stepping frequency
    #endif
  }
}

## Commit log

2017-07-14 Added Bipolar schematic
    [schematic-bipolar.fzz]
2017-07-21 Added BOM list
2017-08-31 New flag to define the direction of the motor rotation
2017-11-19 Adds support for the Arduino IDE
2017-11-21 Updated the schematic and breadboard layout
    [schematic-bipolar.fzz]
2017-12-11 Update the project's documentation
    [schematic-bipolar.fzz, schematic-unipolar.fzz]
2018-01-03 Update the documentation
    [schematic-bipolar.fzz, schematic-unipolar.fzz]
2018-01-03 Added stl info for printing the enclosure
2018-03-15 Stepping optimization for the A4988 driver
2018-03-15 Implemented the remote reset command
    [ardufocus.cpp, config.h]
2018-03-16 Send serial hex value in upper case
2018-05-04 Move sketch to appropriately named subfolder
    The Arduino IDE requires that a sketch be located in a folder of the same name. Although the name of the repository does match the sketch name, when GitHub's popular Clone or download > Download ZIP 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
    When opening a file that does not meet this sketch/folder name matching requirement the Arduino IDE presents a dialog:
    The file "ardufocus.ino" needs to be inside a sketch folder named "ardufocus".
    Create this folder, move the file, and continue?
    After clicking "OK" the Arduino IDE currently moves only the file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
2018-05-17 SGP wrong temp workaround
    [ardufocus.cpp, config.h]
2018-06-08 Stepper classes code improvement
2018-06-15 Migration to timer0 with fixed ISR frequency
    [ardufocus.cpp, assert.h, config.h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]
2018-06-20 Fixes config.h assert errors
    [assert.h]
2018-09-03 Adds support for DRV8825 driver
2018-10-16 Sync default driver pinout to the wiring diagram
2019-01-26 Added Eagle PCB and Schematic
    [ardufocus.brd, ardufocus.sch]
2019-03-25 Quick workaround for __cxa_pure_virtual linker error
    [ardufocus.cpp, isr.cpp, uln2003.cpp]
2019-04-08 motor_is_moving() was not protocol compliant
2019-04-09 Second motor control is fully functional
2019-04-09 A4988 ASCII schematic
2019-04-12 Fixed ISR timming when two motors were active, removed COMPRESSION and some other small fixes
    [ardufocus.cpp, assert.h, hal.h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]
2019-06-17 Fixed a typo on config.h
    [config.h]
2023-11-11 Added speed and stepper mode saving to EEPROM (#35)
    * Added motor speed to EEPROM
    * Added half step mode to EEPROM

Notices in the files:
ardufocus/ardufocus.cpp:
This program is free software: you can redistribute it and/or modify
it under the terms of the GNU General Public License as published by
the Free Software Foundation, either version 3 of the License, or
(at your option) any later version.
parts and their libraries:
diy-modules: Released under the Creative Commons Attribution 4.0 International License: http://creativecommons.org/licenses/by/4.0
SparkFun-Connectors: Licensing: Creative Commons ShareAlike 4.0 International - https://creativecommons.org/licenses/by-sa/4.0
